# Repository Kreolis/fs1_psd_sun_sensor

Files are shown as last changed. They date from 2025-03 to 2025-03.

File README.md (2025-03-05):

# Foresail-1 PSS Sun Sensor

This repository contains the public available design files for the PSS sun sensor designed for the Foresail-1 Cubesat.

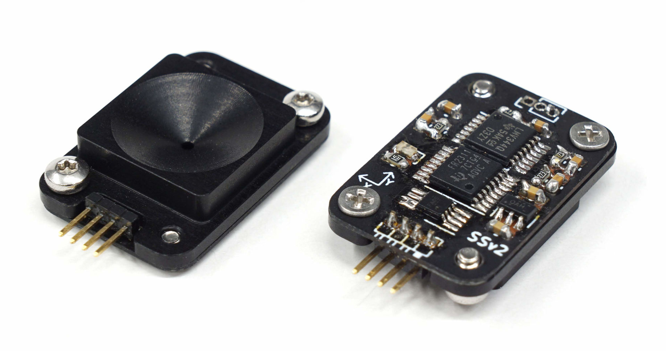
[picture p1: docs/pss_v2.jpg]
PSS Sun Sensor Prototype v2


The general characteristics of sensor design are:
- Dimensions: 24 mm × 16 mm × 6 mm
- Mass: 4 grams
- Panel mountedable into 14x14 mm hole with two M2 screws.
- Electrical connection by soldering on the panel PCB or by harness.
- FOV: ~100 degrees, resolution: 0.13°, accuracy: ±1°
- Refresh rate up to 100 Hz. (Sampling time: 4 ms + communication overhead)
- Can provide following data products:
    - Raw current measurements
    - Point & intensity measurements
    - Sun vector & intensity measurements
    - Angles & intensity measurements
- I2C digital serial interface (hardware version 3)
- RS-485 digital interface (hardware version 4)
- Low power consumption < 4 mW when active
- Nominal operating voltage: 3.6 - 3.8V: Can be extened easily to 2.0 – 5.5 V.

## Documentation

- [FS1 ADCS PSS Sun Sensor Design Document](docs/FS1p_ADCS_PSS_Sun_Sensor_Design_Document.pdf)
- [Version 3 schematic (I2C variant)](v3/pss_v3_schema.pdf)
- [Version 3 firmware source code](v3/fw)
- [Version 4 schematic (RS-485 variant)](v4/pss_v4_schema.pdf)
- [Version 4 firmware source code](v4/fw)
- [Calibration and test tools for PC](calibration)
- [Mechanical design files](mechanical)

## Licence

The design is licenced under [CERN Open Hardware Licence Version 2](LICENCE)

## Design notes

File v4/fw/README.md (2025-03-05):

# Building with Make:

The ti msp build tools can be downloaded from [here](https://www.ti.com/tool/MSP430-GCC-OPENSOURCE#downloads).
==Remember to set the `PREFIX` variable in the Makefile to point to your ti install location!==

requirements: msp-flasher mspdebugger msp430-elf-gcc

Usage:
- `make` compiles the PSD\_SUNSENSOR elf and ihex files
- `make flash` flashes with MSP430Flasher
- `make unlock` Erases user code from the device and unlocks debugger
- `make debug` Flashes the device, starts mspdebug gdb server and launches a gdb client

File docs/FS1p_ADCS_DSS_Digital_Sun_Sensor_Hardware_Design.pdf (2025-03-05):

## PSS Sun Sensor Design

FS1p ADCS PSS Sun Sensor Design

Responsible: Petri Niemelä Version date: 2023-10-18
Page: 1 / 23

# Foresail-1p

# PSS Sun Sensor Design

# Aalto University

## Department of Electronics and Nanoengineering

Page: 2 / 23

### Authors

Name | Worked with parts
Petri Niemelä | The whole document
Marius Anger | Foresail-1p revision 4

### Table of Contents

1 General | 4
1.1 Scope | 4
1.2 Applicable Documents | 4
1.3 Reference documents | 4
1.4 Abbreviations and acronyms | 4
2 Sensor Design | 5
2.1 Performance | 6
2.2 Sun vector estimation | 9
3 Electrical Design | 10
3.1 Electrical Interface | 10
3.2 Microcontroller | 10
3.2.1 Radiation Hardening | 11
3.3 Transimpedance Amplifiers | 11
3.4 Analog Digital Converter | 14
3.5 Power supply | 14
3.6 I2C bus isolation | 14
3.7 Operating environment | 15
4 Mechanical Design | 16
4.1 Mechanical Interface | 16
5 Digital interface | 17
5.1 I2C Commanding Protocol | 17
5.2 RS-485 Commanding Protocol | 17
5.3 Command set | 17
6 References and further reading | 19
7 Appendices | 21
7.1 Schematics | 21
7.2 Bill of Material | 21
7.3 PCB layout | 22

Page: 3 / 23

## 1 General

### 1.1 Scope

This document represents a detailed design of the PSS Sun Sensor designed for FORESAIL-satellites. This document applies for hardware version v3 (I2C variant) and v4 (RS-485 variant).

The public design files can be found from Github-repository: https://github.com/foresail/fs1_psd_sun_sensor

### 1.2 Applicable Documents

[AD-01] FS1 ADCS PSS Sun Sensor Prototype Test Plan (https://docs.google.com/document/d/1LfsjXxHAqfksmW_5qAY_K_lkndrjo7vK9R7hFGDcjuA/edit)

[AD-02] FS1 ADCS PSS Sun Sensor Qualification Test Report template (https://drive.google.com/open?id=1y2Mrd9W40DUWGKvcDPNy5vSXA1CmaDOZ_xgLSq9taWw)

FS1 Internal Communication Protocol DRAFT (https://docs.google.com/document/d/1XI1juZfPpQ4f6fcUQnDhy1BJxTMV3S1bdBzDqWCUd_g/edit)

### 1.3 Reference documents

[RD-01] Hamamatsu S5990-01 Two-Dimensional PSD
datasheet: https://www.hamamatsu.com/resources/pdf/ssd/s5990-01_etc_kpsd1010e.pdf

[RD-02] Texas Instrument’s MSP430FR231x Mixed-Signal Microcontrollers datasheet: http://www.ti.com/lit/ds/slase58d/slase58d.pdf

[RD-03] Texas Instrument’s OPAx340 Single-Supply, Rail-to-Rail Operational Amplifiers datasheet: http://www.ti.com/lit/ds/symlink/opa4340.pdf

### 1.4 Abbreviations and acronyms

ADC | Analog-to-Digital Converter
FRAM | Ferroelectric Random Access Memory
FOV | Field Of View
MCU | Microcontroller
PCB | Printed Circuit Board
PSD | Position Sensitive Detector/Device
TIA | Transimpedance Amplifier
WDT | Watchdog Timer

Page: 4 / 23

## 2 Sensor Design

The PSS sensor (Position Sensitive Sun sensor) is a light sensitive photodiode which produces a small current when exposed to light. The PSS differs from the normal photodiode by having four cathodes and one anode for one single large detector area. When the sensitive area is illuminated with a relatively small spot of light the produced currents are distributed depending on the position of the light spot. When the light spot is created using a pinhole structure the sensor can be used to measure direction/angle of the incoming light and thus the concept can be applied for making a sun sensor.

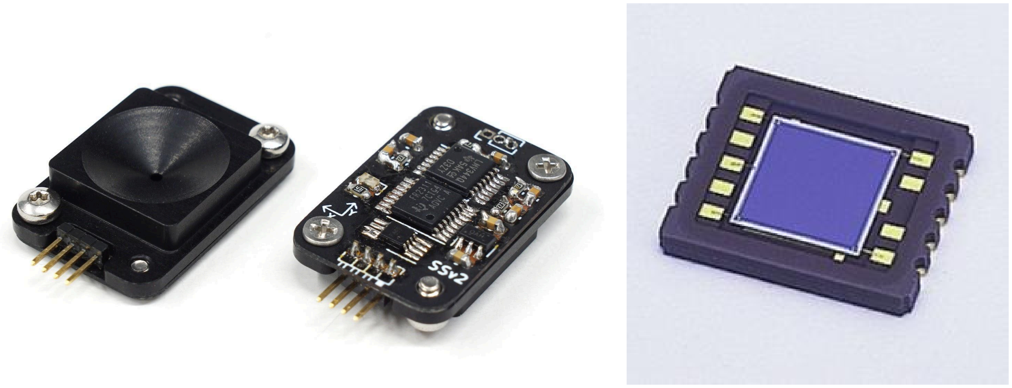
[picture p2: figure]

Figure 1: PSD Sun Sensor version 2 and Hamamatsu S5990-01 Position Sensitive Device

The used PSS, Hamamatsu S5990-1, (In Figure 1) is so called tetra-lateral type (pin-cushion type) that delivers improved position detection and linearity compared to other similar diodes. The sensor has a large 4 × 4 mm active area. [RD-01]

PSS sensors advantages in sun sensor application can be considered: simple electrical and mechanical design and easily achievable large Field of View (FOV). The sensor design's largest disadvantage is its sensitivity for stray light meaning that the sensor cannot discriminate between direct sunlight and reflected sunlight. Reflections, for example from moonshine or earthshine, cause bias error which cannot be easily eliminated from the measurements. Effect of this will be discussed later in detail.

The general characteristics of sensor design are:
- Dimensions: 24 mm × 16 mm × 6 mm
- Mass: 4 grams
- Panel mountable into 14x14 mm hole with two M2 screws
- Extension behind the panel: 3.1 mm
- Electrical connection by soldering on the panel PCB or by harness.
- FOV: ~100 degrees, resolution: 0.13°, accuracy: ±1° (discussed in the following sections)
- Refresh rate up to 100 Hz. (Sampling time: 4 ms + communication overhead)
- Can provide following data products:
- Raw current measurements
- Point & intensity measurements
- Sun vector & intensity measurements
- Angles & intensity measurements
- I

2C digital serial interface (applicable for hardware version 3)

Page: 5 / 23
- Maximum bus speed 400 kHz at 3.3V logic level.
- I

2C address can be configured via the command interface.
- The I

2C bus is isolated when the sensor is unpowered.
- RS-485 digital interface (applicable for hardware version 4)
- Follows reduced Foresail multi-drop RS-485 protocol definition
- Half duplex RS485 transceiver via MCU UART
- Low power consumption < 4 mW
- Sleep: 0.45 mA @3.6 V
- Sampling: 0.9 mA @3.6 V
- Peak sampling: TBD mA @3.6V
- In-rush current: TBD mA @3.6V
- Operating voltage: 2.0 – 5.5 V
- The standard version has a 3.3V LDO and designed operating voltage is around 3.6V.
- MSP430 can operate with voltages down to 1.8 V.

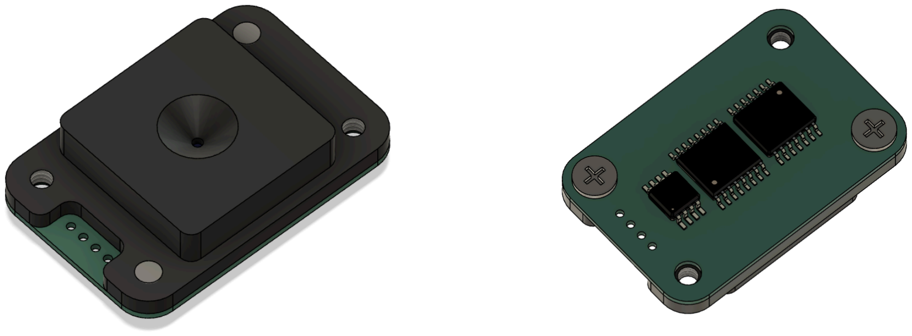
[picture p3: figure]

Figure 2: Front and back side of the PSD Sun Sensor assembly from CAD program.

### 2.1 Performance

The performance (FOV and accuracy) of the sensor is mainly determined by the geometry of the pinhole structure. The pinhole geometry is illustrated in the following figure. By adjusting the distance of the pinhole from the sensor. On the Foresail-1 PSD Sun Sensor the distance from photodiode to pin hole is 1.50 mm.

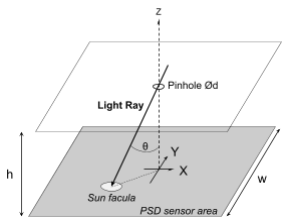
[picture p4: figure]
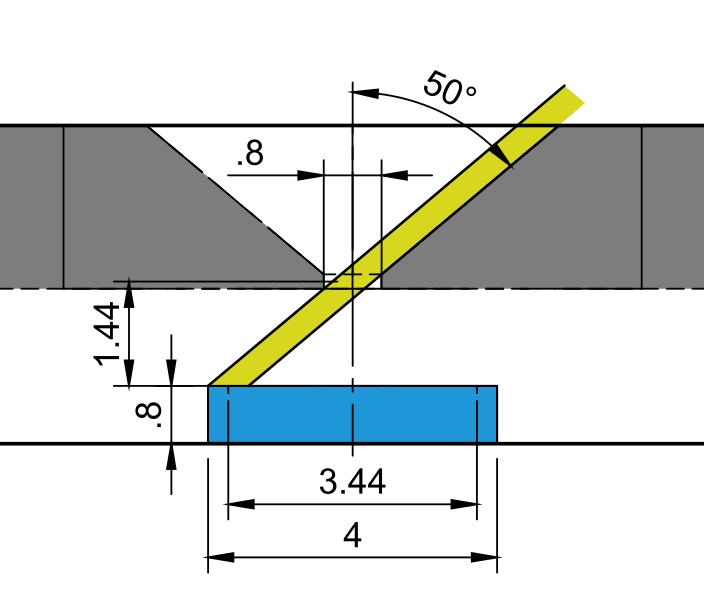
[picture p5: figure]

Figure 3: On left the sensor’s pinhole geometry illustrated in 3D. On the right the sensor’s actual pin hole geometry with dimensioning.

Page: 6 / 23

Field of View:
The maximum field of view of the sensor is determined by its tan( FoV/2 ) =

0.5*(w − d)
ℎ | =

0.5 * 3 mm
1.26 mm ⇒ FoV = 100°
In practice the sensor has an even larger FOV. (see calibration results)

Resolution:
When using 10 bits (1024 counts) per channel and because there are two channels per axis, each axis is “sampled” in 11-bit resolution. Thus, at the center of the sensor the theoretical resolution is:

θ = atan(

(3 mm / 1024)
1.26 mm

) ≃ 0. 134°

This resolution improves when moving toward the edge of the sensor. Smaller angle changes in the Sun direction causes larger changes in light spot position. At the edge the theoretical resolution is:

θ = atan(

0.5 * 3 mm
1.26 mm

) − atan(

0.5 * 3 mm * 511/512
1.26 mm

) ≃ 0. 055°

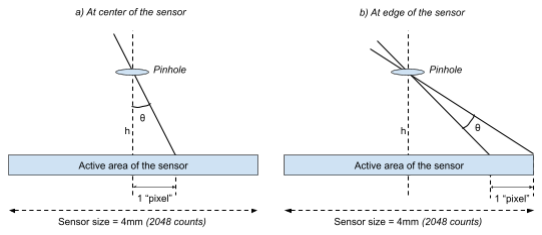
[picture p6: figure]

Figure 4: Resolution estimated using simplified pin hole geometry.

In theory, the resolution doesn’t depend on the size of the light spot until the light spot is clipped by the edge of the active area of the sensor. The output currents and the current distribution depends on the intensity of the light and the “mass center” of the light. If the light spot size is increased its mass center stays the same. Only the intensity (amount of light passing through the pinhole) changes. The sensor’s gain can be adjusted using for any pinhole

Real accuracy:
In theory the sensor could achieve better than 0.15° accuracy but in practice the accuracy is not that good and it is affected by numerous error sources. In this section some of those error sources are analyzed.
In practice the resolution of PSD based sensors varies between around 1 - 5°. If someone claims better accuracy (with similar FOV and single sensor) than this when using the same sensor technology, they most likely lie or don't tell the whole truth.

Error sources:
1) The sensor cannot differentiate between different sources of light: Sun, moon, Earth’s Albedo, specular reflections from the Earth’s surface. Discussed in detail in the next section.

Page: 7 / 23
2) The pinhole structure is not a perfect pinhole. Incoming light can reflect from the edge hole and cast a second light spot. Black anodisation aims to cope with this problem.
3) At high angles the cover glass can refract the light spot. This effect can be partially calibrated.
4) The light spot can reflect from the cover glass and bounce inside the sensor. The error caused by the reflections inside the sensors are tried to minimize by anodizing the sensor cover black.
5) The response of the PSD is not completely linear aka current distribution doesn’t map the light spot position perfectly. This happens both in axis and diagonally mapping. Hamamatsu’s tetra-lateral type (pin-cushion type) PSD aims to compensate for this.
6) The ADC is not perfect and it has noise on its results. According to the MCU’s datasheet ADC Effective error in 10-bit mode is ±2 LSB (least significant bits). Based on this the accuracy is less than 0.3°. ADC noise could be reduced by using oversampling because the sampling noise is gaussian by its nature. This is not seen beneficial because other error sources are more dominant and multi-sampling would just slow down the sampling.
7) Thermal expansion of the components is not considered. The surface temperature of the satellite can vary between -40°C and 40°C. The sensor cover should have a mirror finish on its front side to minimize heat load.
8) Sensor mounting on the satellite structure easily introduces a significant systematic error which is larger than the accuracy of the sensor. Calibrating the sensor position/orientation relative to the satellite’s coordinate system should be performed after final assembly but such test setup is not simple.

Effect of the straylight:
PSS’s greatest disadvantage is its incapability to differentiate between different light sources. The currents generated by different light sources (Sun, Earth, Moon shine and specular reflections from Earth’s surface) sums up together and cannot be separated from each other. Thus, Earth’s and Moon’s albedos add a bias error into Sun direction estimation if they are visible at the same time. Because each satellite’s face has a dedicated sun sensor and only the strongest signal is taken into consideration in sun vector determination, the Earth’s albedo affects the sun vector measurements only when the Sun and Earth are inside the same 90° FOV “pyramide”. This happens when the satellite is above 66’th latitude (north or south) and ±24° around the termination zone. The influence of Earth’s albedo is constantly on sun synchronous orbit, which Mean Local Time of the Ascending Node (LTAN) is between 04:24 - 08:36 and 16:36 - 19:24. These regions are illustrated in the Figure 5.

Page: 8 / 23

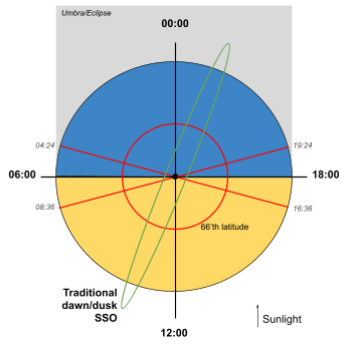
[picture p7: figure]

Figure 5: Orbit regions where PSD’s operation is affected by Earth’s albedo.

The effect of Earth’s albedo to the accuracy of PSD sun sensor is greatly discussed in Rober Valner’s bachelor’s thesis: http://dspace.ut.ee/bitstream/handle/10062/30981/Robert_Valner.pdf In his thesis he concludes that: “the net uncertainty of the measurements of the sensor is 2.5° with coverage probability of approximately 95%”

Intensity accuracy:
The intensity measurement of the sensor is relative and should not be used as absolute measurement. The sensor’s intensity output is the average of each channel's output in range from 0 to 1024. The reading highly depends on the sensor’s temperature due to photodiodes efficiency characteristics and temperature drift of the voltage reference.

The intensity reading itself could be also used to determine the sun angle using inverse cosine law and with temperature compensation using the MCU’s temperature sensor could provide better absolute accuracy but this is implemented because it’s not seen beneficial for an attitude control system as whole. The linearity of the intensity measurement is not known.

What could be improved?
Possible methods to improvement accuracy:
1. More sensors with smaller FOV
2. Add UV bandpass filter to remove the effect of albedo and specular reflections.

### 2.2 Sun vector estimation

The determination of the sun vector from multiple sun sensors can be done using following simple algorithm:
meas = get_all_sun_vectors()

sun_detected = false
sensor_i = arg_max(meas.intensity)
if meas[sensor_i].intensity > detection_threshold:

Page: 9 / 23

sun_direction = apply_rotation(sensor_i, meas[sensor_i].vector) sun detected = true

## 3 Electrical Design

The electrical design of the sensor is very simple. It consists of a PSD sensor itself (aka four channel photodiode), four transimpedance amplifiers and a MCU for analog to digital conversion and digital communication.

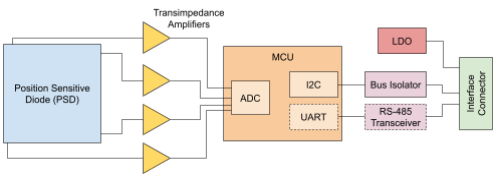
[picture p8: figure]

Figure: Block diagram of the sensor's electrical components and their connections.

### 3.1 Electrical Interface

The sensor’s electrical interface is described in the table below.

Table: Sensor pinout
Pin number | Pin name on version 3 | Pin name on version 4
1 | GND | GND
2 | VCC | VCC
3 | I2C SDA | RS-485 DATA+
4 | I2C SCL | RS-485 DATA-

On the PCB the electrical connection is done to the 1.27 mm pitch pin 4 hole connector footprint. To this footprint the electrical connection can be done by directly soldering the sensor on a PCB panel using a right angle 1.27mm pin header or by soldering a pigtail cable on it.

### 3.2 Microcontroller

The PSS’ MCU is Texas Instrument’s MSP430FR2311IPW16. MCU’s important features are: [RD-02]
- Small TSSOP-16 package
- Runs at 4 MHz
- 3.75KB of Program FRAM (Radiation Resistant and Nonmagnetic) + 1KB of RAM
- Internal 1.2V voltage reference
- 8 channel 10-Bit Analog-to-Digital Converter (ADC) with internal 1.5V voltage reference

Page: 10 / 23
- Optimized low power modes (32nA in shutdown)
- Wide support for serial communication protocols such as I

2C, UART etc.
- Internal brown-out detection circuit

The selected MCU has also internal opamp which could have been used for something.

### 3.2.1 Radiation Hardening

Following radiation hardening are considered in the design:

### 1. Usage of system FRAM memory:

The selected MCU uses FRAM technology for storing its firmware. The FRAM technology is known from its radiation hardness on a memory cell (SEU: Single Event Upsets). This doesn’t ensure complete radiation hardness against other types of single events. Single events can also happen in the memory controllers etc.

Also the sensor is vulnerable to destructive single events burnouts if no latching.

The dose tolerance of the MCU is not known and it could be generalized outside of a single batch.

### 2. Watchdog Timer:

Watchdog resets the MCU every ~40 seconds if the main loop stops running. Heartbeat timer tries to wake up the processor every 70 ms to execute the main loop.

### 3. Register refreshing by resetting:

Sensor initializes itself every 2 minutes in nominal state to refresh all internal peripheral registers.

### 3. Component-level power cycling:

The opamp’s power is supplied from MCU’s IO-pin which works as current limiter and load switch and it can be used to cycle on every reset.

### 4. Sensor Aluminium shielding

At the surface of the satellite, the sensor experiences a harsher radiation environment compared to the rest of the electronics on board inside the radiation shielding. To compensate this a little bit, the thickness of the aluminum sensor cover has not been minimized to give some protection against total dose effects. The only way to improve this more is to move the electronics beside the PSD photodiode itself inside the satellite.

### 3.3 Transimpedance Amplifiers

For PSD sensor current measurement the sensor board has four transimpedance amplifiers (TIA) to perform current-voltage conversion with predefined gain. The amplifier gain is set by the external resistor and adjusted depending on illumination levels, hole size etc. Photodiodes are in zero reverse bias configuration for improved sensitivity at low intensities. Additionally, a filtering capacitor is placed parallel on the feedback loop to cut-off frequencies above 100 Hz.

When the current is zero the opamp outputs the reference voltage and higher the current lower the output voltage is. The output voltage can be then measured by the ADC. MSP430’s internal voltage reference (VREF+) is used for the opamp. The precision of the voltage reference doesn’t affect the overall point position measurements. The possible reference voltage drift affects only absolute

Page: 11 / 23
intensity measurements and is the same for all the channels. The point position is calculated from the differences of absolute current measurement as defined in equation X, and thus, possible reference voltage drift won’t affect sun vector accuracy. The absolute illumination is not sure for sun vector determination. Also, the diode’s leakage current will vary based on the temperature.

On hardware version 4 (RS-485 variant), the MSP430’s internal voltage reference cannot be used due to pin mapping collision with an UART pin required for RS-485 transceiver. Thus, an external voltage reference is required for the opamps. There are no real requirements for the reference other than voltage should be such that the opamp doesn't need to drive till the rail voltage. Absolute stability is not required because the intensity measurements are already relative by their nature and the reference is shared between the channels. Also the voltage reference is connected to very high impedance (only opamps inputs), so the current draw is negligible. Thus, to keep the BOM and PCB layout simple a simple 1:1 resistor divider was chosen to generate 1.65 V reference. The resistor divider as voltage reference is sensitive for source voltage but in this case the 3.3V source voltage is regulated very close to the divider itself.

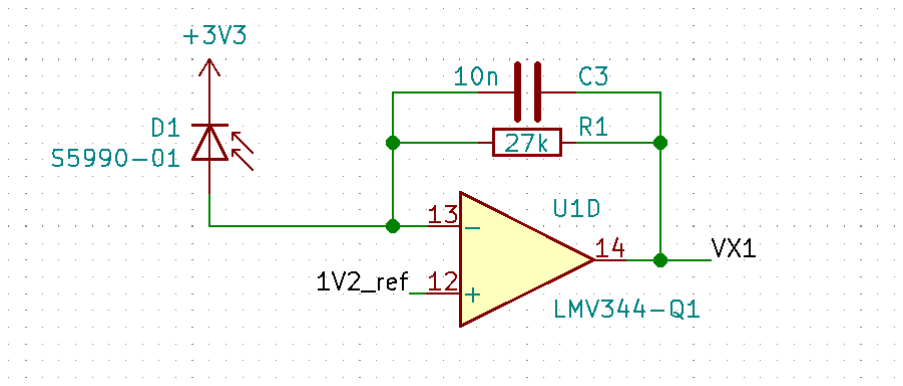
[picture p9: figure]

Figure 6: Simplified circuit diagram of a transimpedance amplifier.

The chosen operational amplifier is automotive quality LMV344-Q1 quad rail-to-rail output CMOS operational amplifier in small TSSOP-14 package [RD-03]. The opamp has relatively narrow bandwidth (1 MHz), low power consumption 100 µA (typical). Measured current consumption in dark: 230 µA. (0.83 mW @3.6 V)

Opamp’s positive rail is at 3.3 V and negative at GND. The opamp is powered from MCU’s GPIO pin thus can be turned to save even more power. This is possible due to the low power consumption of the opamp.

The response of the transimpedance amplifier circuit was simulated using LTspice simulation program. The simulation model is illustrated in Figure 7. The model was used to confirm the AC response of the filter (Figure 8). Also, an input waveform for the photodiode current source was generated using a simple Python script. The amplifier circuit’s time domain response when attach on a satellite spinning at 1 Hz can be seen in Figure 9.

Page: 12 / 23

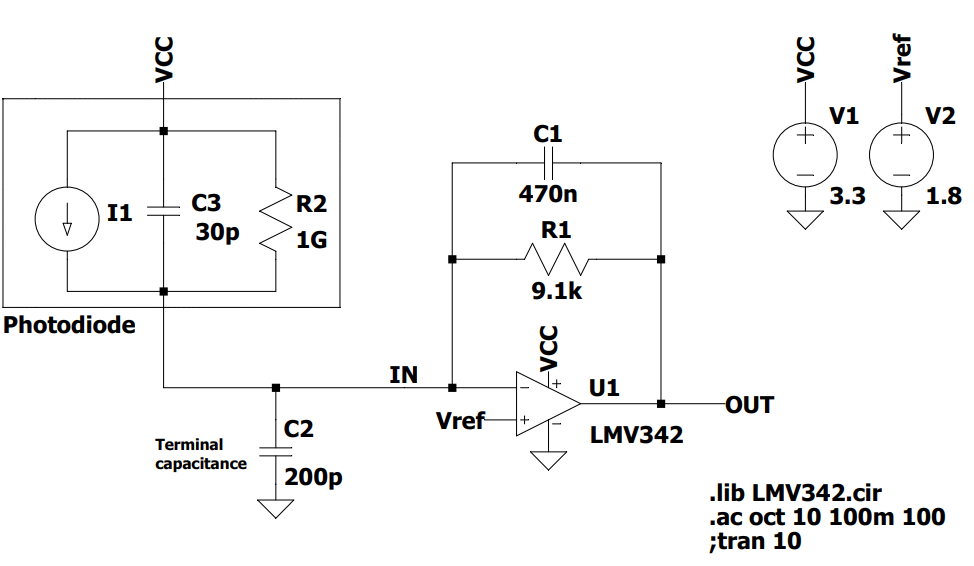
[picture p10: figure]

Figure 7: LTSpice model used to simulate the transimpedance amplifier transient and AC responses. (The used LMV342 opamp is identical LMV344 but has different number of channels)

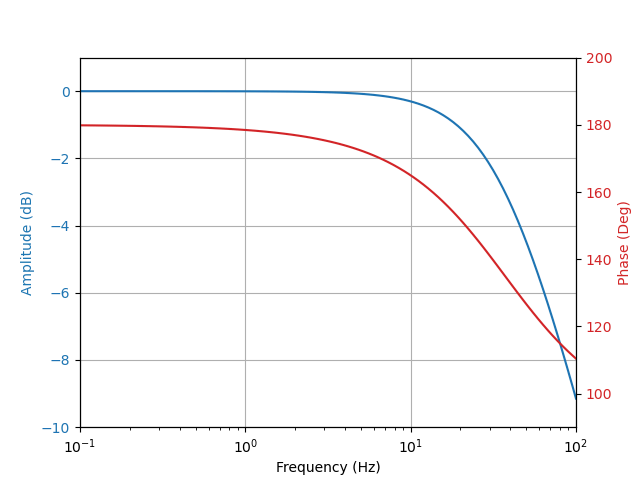
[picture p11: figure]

Figure 8: The AC response of the transimpedance filter. The -3dB cutoff frequency is around 37 Hz.

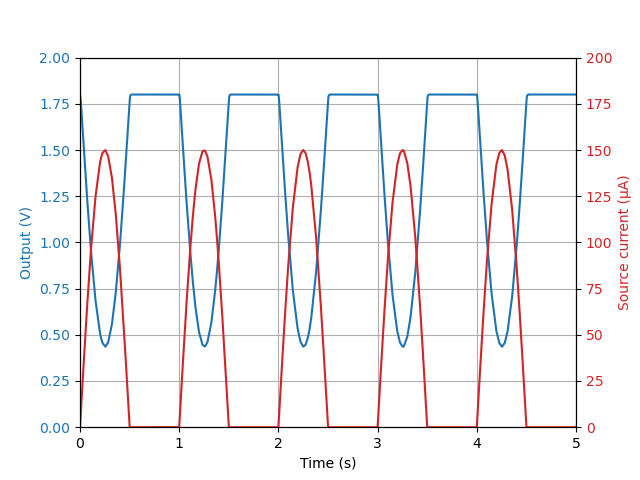
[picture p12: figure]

Figure 8: Transient response of the TIA for 1Hz (60 rpm) spin. The output voltage response is inverted compared to the produced current of the photodiode due to the reverse bias design. Small amount of smoothening can be seen on the trailing edge due to low pass filtering.

Page: 13 / 23

### 3.4 Analog Digital Converter

The analog to digital conversion is done using MSP430’s internal 8-channel 10-bit ADC and the analog lines are referenced against MSP430’s 1.2 V reference (VREF+) which is externally connected to ADC’s VEREF+ -pin.

The ADC samples the different voltage channels in sequence and not simultaneously. The small sample time difference is considered to be negligible for the precision of the sensor. For a satellite spinning at 1 Hz, the satellite attitude changes 1.1° during the 3 ms sampling time.

Temperature sensor: MSP430 has an internal temperature sensor which is connected to ADC’s channel 12. Temperature sensor voltage is compared to ADC’s internal 1.5 V reference. The maximum temperature the sensor can measure is roughly 170°C. Above this temperature the sensor voltage goes above 1.5 V.

ADC count to temperature is thus coefficient:
3. 35 mV/°C ⇒ (1500mV / 1024 counts) / 3. 35mV/°C = 4. 37° dC/count

Equation on the MCU:
T(°dC) = (ADCcount − calib) / 4 °dC/count + 300°dC

### 3.5 Power supply

The sensor is designed to take 3.6 V input voltage and has 3.3 V low dropout voltage (LDO) regulator on board. Lower voltages are possible down to 2.5V with the same opamp or down to 1.5 V the opamp is changed to a similar kind of with lower input voltage rating. The LDO can be also bypassed with a 0-ohm resistor if wanted.

### 3.6 I

### 2C bus isolation

Sun sensor uses SN74TVC3306 bus level translation IC as I

2C bus isolator to prevent stalling the I

2C bus when the sensor is not powered. The isolator also prevents the sensor from being powered via the SDA/SCL lines due to low power consumption of the MSP430 processor. The isolator IC is basically three individual NMOS transistors (also called dual voltage clamp) and can be considered robust design for higher radiation environment. The down side of this type of isolator is the 3.5 ohm high’ish series resistance.

Page: 14 / 23

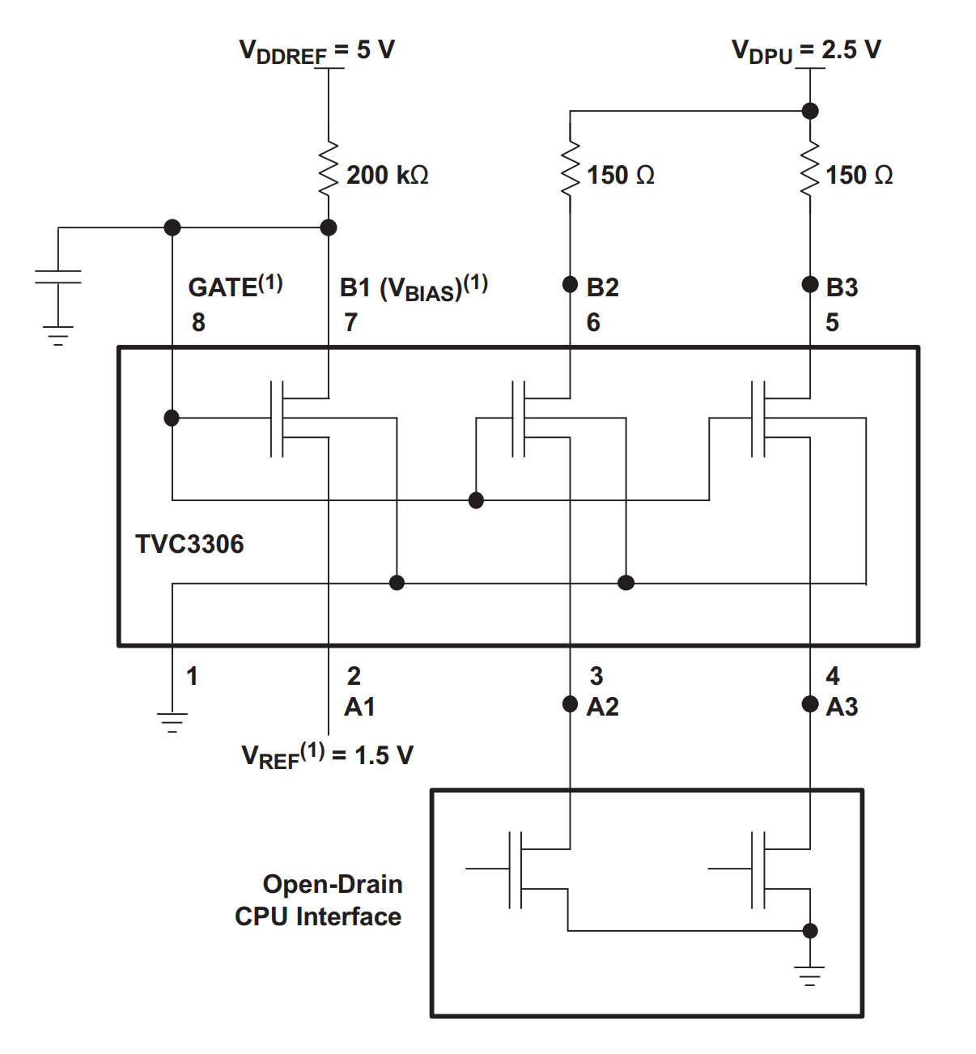
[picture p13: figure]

Figure 9: Internals of the SN74TVC3306 IC used for the I2C bus

### 3.7 Operating environment

The PSS are expected to encounter large temperature variations in the low earth orbit conditions on the surface of the satellite. On the surface of the satellite, sensors are exposed to direct sunlight and cold space in turns with very little thermal inertial and poor thermal conduction to the rest of the satellite's structure. It has been estimated that the surface temperatures of the cubesat in LEO will at least vary from -20 to 30 °C on every orbit and in the worst case -40°C to 60°C.

The recommended operating temperature ranges for each component can be seen in the following table. The most limiting recommended temperature range is for Hamamatsu's PSD diode whose lower temperature limit is -20°C. Low temperatures doesn’t inherently degrade the electrical performance of a diode but the diode’s packaging method might be the reason for the lowered rating. (Maybe the manufacturer hasn’t just performed the qualification test for lower temperatures.) There are no huge concerns to suspect that the diode would fail right after -20°C. Also, thermal vacuum verification tests with -40 to +100°C temperature range are performed for all the PSS assemblies at subsystem level.

Table: Off-the-self component environment ratings
Component | Recommended Operating Temperature
Hamamatsu S5990-01 | −20°C to +60°C
MSP430FR2311IPW16 | −40°C to +80°C
LMV344-Q1 | −40°C to +125°C
TLV71333P-Q1 | −40°C to +125°C
SN74TVC3306 | −40°C to +80°C

Page: 15 / 23

THVD14xx | −40°C to 125°C

The sensor PCBs are ordered with higher Epoxy glass transition temperature (Tg=170-180°C) to make sure the PCB can tolerate high temperature cycles and won’t fracture or de-laminate due to material expansion.

Note: A single case of sensor stopping working at temperatures higher than 50°C has been observed. The root cause of the problem was never investigated but it was clearly an analog side failure. The sensor recovered by itself when the temperature decreased below 50°C.

## 4 Mechanical Design

Sensor’s main structural component is the aluminum sensor cover which also works as the pin hole structure for the photodiode. The 0.5mm thick back PCB attaches to the sensor cover using two M2x2 screws and the whole assembly has been designed to be mounted on the panel (Aluminum plate or PCB).

The sensor cover has four M2 threaded holes in total. Two of these are used for attaching the PCB to the cover and other two are used to attach the whole assembly to the panel. Mounting to the panel can be done for example with two M2x4 screws. In Figure 10 the sensor’s overall dimensions and the locations of the attachment holes can be seen.

Either of the diagonals can be used for attaching the PCB and for sensor mounting. See preferred from Figures 1 and 2.

### 4.1 Mechanical Interface

The sensor’s mechanical interface can be seen in the figure below.

Page: 16 / 23

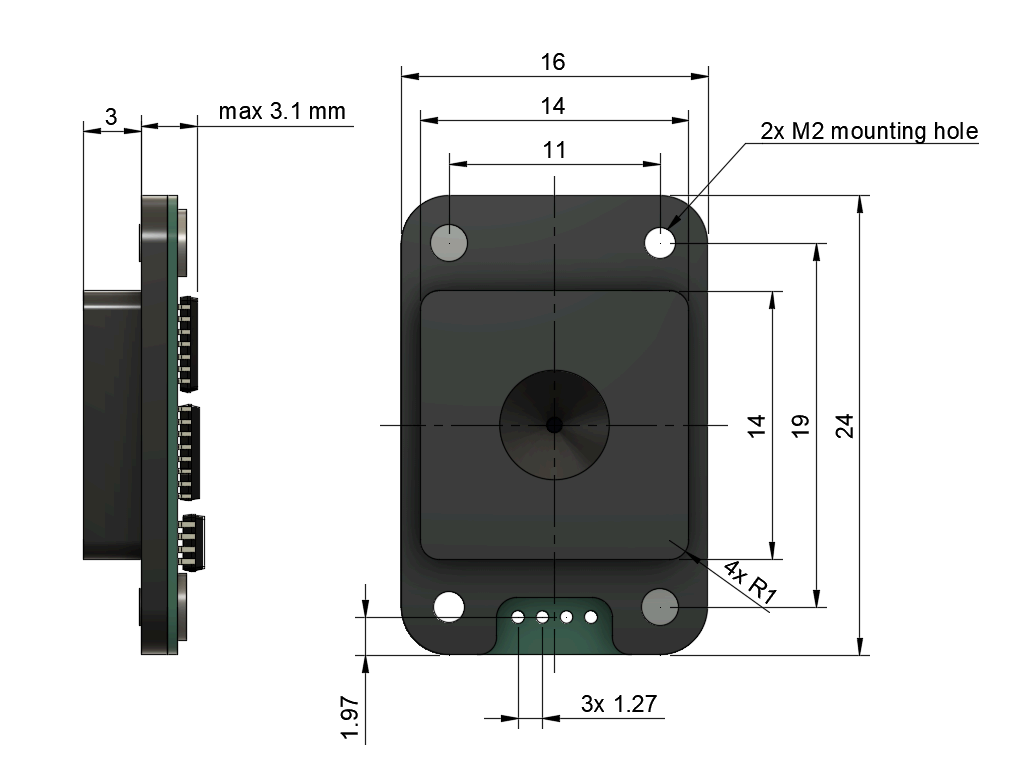
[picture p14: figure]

Figure 10: Required panel cut out for the module.The preferred holes for panel mounting are top-right and bottom-left holes.

The sensor is designed to be mounted on a 14x14mm size rectangular hole whose corner has 1mm rounding.

Note: Due to the small size of the sun sensor, the mounting/remounting accuracy of the sensor is not very high. Thus, the sensor's relative orientation to the satellite’s reference frame should be calibrated after the final integration.

## 5 Digital interface

This section defines the I

2C and RS-485 digital interfaces and the command set over the bus.

### 5.1 I

### 2C Commanding Protocol

Sensor’s digital interface uses the I

2C protocol where the sensor works as a slave. Default I

2C
address is 0x6A and the slave address can be set when reprogramming the sensor or using the I

2C
commands. Sensor implements a simple I

2C protocol which follows the standard I

2C data structure
and defines the first transmitted byte as a command byte which identifies the command or the response. The protocol commanding and response structure are illustrated in Figure 11.

Page: 17 / 23

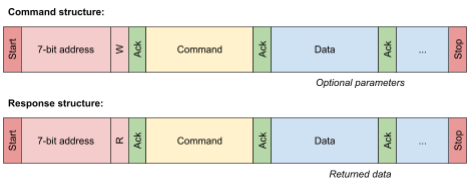
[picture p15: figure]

Figure 11: I

2C command and response structures

Remarks:
- The default address range for the sensors is: 0x4A - 0x4F
- If the I

2C master tries to read the response before the sensor is ready the slave will answer by sending 0xFF.

### 5.2 I2C Command set

List of PSD Sun Sensor commands and their functionalities

Remarks:
- Commands which do not return a special data structure return a status code with status command code (0x01).
- All the multi byte integers are in little endian format (most significant byte is last).
- If there is no I

2C communication on the bus in 2 seconds the MCU will turn off the opamp, voltage references and ADC to save power and unbiased the analog components.

0x01: Status
Read len: 1
Returns response code RSP_OK (0xF0) or RSP_SLEEP (0xF1).

0x03: Get Raw
Runs measurement sequence and returns raw current readings. Read len: 9

typedef struct { // size() = 8 bytes
uint16_t vx1; // Range: 0 - 1024 uint16_t vx2; // Range: 0 - 1024 uint16_t vy1; // Range: 0 - 1024 uint16_t vy2; // Range: 0 - 1024 } raw_measurements_t;

0x04: Get Position
Runs measurement sequence and returns measured light sport position and intensity.

typedef struct { // size() = 6 bytes
int16_t x; // -1024 - +1024

Page: 18 / 23

int16_t y; // -1014 - +1024 uint16_t intensity;
} position_measurement_t;

0x05: Get Angles
Runs measurement sequence and returns measured angles and intensity.

typedef struct { // size() = 6 bytes
int16_t ax; // Desidegrees int16_t ay;
uint16_t intensity;
} angle_measurement_t;
Note: The command uses 128 items look-up table and linear interpolation for angle calculation.

0x06: Get Vector
Runs measurement sequence and returns measured sun vector and intensity.
typedef struct { // size() = 8 bytes
int16_t x, y, z;
uint16_t intensity;
} vector_measurement_t;
Note: The reported vector is a direction vector toward the Sun aka signs of the X and Y point positions have been flipped.

0x07: Get All
Runs measurement sequence and returns all three data types listed above (raw, position, angles) Generally used for testing and verification purposes.
Read len: 21

0x08: Get Temperature
Return MCU temperature as 16-bit signed integer in desi-celsiuses aka 23.5°C = 235. Read len: 3 Sampling the temperature takes 1.54ms!

Note: If the temperature calibration offset is set to 0. This function will return the raw ADC count.

0x10: Set Calibration
Set calibration structure.
typedef struct {
int16_t offset_x, offset_y; int16_t height;
int16_t samples;
int16_t temperature_offset; } calibration_t;

0x11: Get Calibration
Returns the same calibration structure as described for “Set Calibration” command. Read len: 11

0x12: Set LUT
Set angle look up table values.
TBC

Page: 19 / 23

0xE8: Set I2C Address
Set a new I2C address for the sensor. To be applied a power cycling is required.

Note: Exact sampling time of sensor depends on the temperature due to temperature dependency of the internal clock.

### 5.3 RS-485 Commanding Protocol

Sensor’s digital interface uses the RS485 protocol where the sensor works as a client on the bus. Default RS485 address is 0xA5 and the address has to be set during the flashing of the device. Sensor implements the Foresail RS485 bus protocol. The protocol message scheme for commanding and response is illustrated in Figure 12.

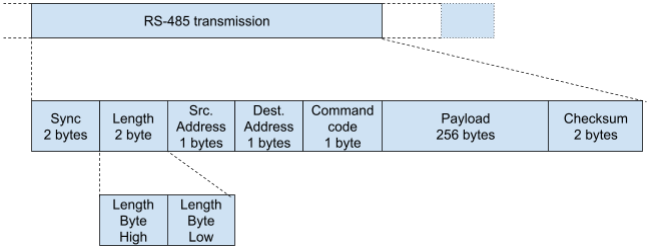
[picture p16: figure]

Figure 12: RS485 communication scheme

Remarks:
- The default address range for the sensors is: 0xA5 - 0xAA
- In the data stream the big-endian format shall be used unless specified. Most significant byte first must be sent for every multibyte word.

### 5.2 RS485 Command set

PSD Sun Sensor commands for RS485 are slightly different as less memory could be used for them as the bus implementation takes up more space.
Additionally, the commands have been unified as much as possible with the digital sun sensor (FS1p ADCS Digital Sun Sensor Hardware Design). (https://docs.google.com/document/d/1M4EdYB_b5ulZ9_kio8c96CQkCGD8mta-0tUQDGEhYco/edit?pli=1)

Remarks:
- Commands which do not return a special data structure return a status comman with status code.
- OK | = 0xF0
- SLEEP | = 0xF1
- UNKOWN_COMMAND | = 0xF2
- INVALID_PARAM | = 0xF3
- ERROR | = 0xF4

Page: 20 / 23
- SAMPLING_ERROR | = 0xF5
- DIVISION_ERROR | = 0xF6
- NOT_ODD | = 0xF7
- CLAC_ERROR | = 0xF8
- All the multi byte integers are in little endian format (most significant byte is last).

0x01: Get Status
Read len: 1
Returns response code RSP_OK (0xF0) or RSP_SLEEP (0xF1).

0x02: Get Raw
Runs measurement sequence and returns raw current readings. Read len: 9

typedef struct { // size() = 8 bytes
uint16_t vx1; // Range: 0 - 1024 uint16_t vx2; // Range: 0 - 1024 uint16_t vy1; // Range: 0 - 1024 uint16_t vy2; // Range: 0 - 1024 } raw_measurements_t;

0x03: Get Position
Runs measurement sequence and returns measured light sport position and intensity.

typedef struct { // size() = 6 bytes
int16_t x; | // -1024 - +1024
int16_t y; | // -1014 - +1024
uint16_t intensity;
} position_measurement_t;

0x04: Get Vector
Runs measurement sequence and returns measured sun vector and intensity.
typedef struct { // size() = 8 bytes
int16_t x, y, z;
uint16_t intensity;
} vector_measurement_t;
Note: The reported vector is a direction vector toward the Sun aka signs of the X and Y point positions have been flipped.

0x07: Get Temperature
Return MCU temperature as 16-bit signed integer in desi-celsiuses aka 23.5°C = 235. Read len: 3 Sampling the temperature takes 1.54ms!

Note: If the temperature calibration offset is set to 0. This function will return the raw ADC count.

0xA1: Get Config
Get config values of specified command.
Following commands are available for the PSD:
CALIBRATION = 0xB1

Page: 21 / 23
0xA2: Set Config
Set config of specified type to the PSD. Following types are available: CALIBRATION = 0xB1

typedef struct {
int16_t offset_x, offset_y; int16_t height;
int16_t samples;
int16_t temperature_offset; } calibration_t;

## 6 References and further reading

References outside of the project:
1. P. Rodrigues, P. Ramos, “Design and characterization of A sun sensor for the SSETI-ESEO project”
http://citeseerx.ist.psu.edu/viewdoc/download?doi=10.1.1.515.3785&rep=rep1&type=pdf
2. C. Avsar, J. Lieb, W. Frese, M. Herfort, and S.Trowitzsch, “Verification of a new two-dimensional sun sensor with digital interface on a sounding rocket.” http://rexusbexus.net/wp-content/uploads/2015/06/tupex-3_sse_symposium_paper_expert_panel_version.pdf (http://rexusbexus.net/wp-content/uploads/2015/06/tupex-3_sse_symposium_paper_expert_panel_version.pdf)
3. L. Lin, Z. Sitong, T. Luyang, W. Dong,“Sun sensor design and test of a micro satellite”, https://www.jvejournals.com/article/17518
4. D. Faizullin, K. Hiraki, HORYU-IV team, M. Cho, “Optimization of a Sun Vector Determination for Pinhole Type Sun Sensor”, http://oaji.net/articles/2017/1330-1507024153.pdf

Page: 22 / 23

## 7 Appendices

### 7.1 Schematics

Version 3

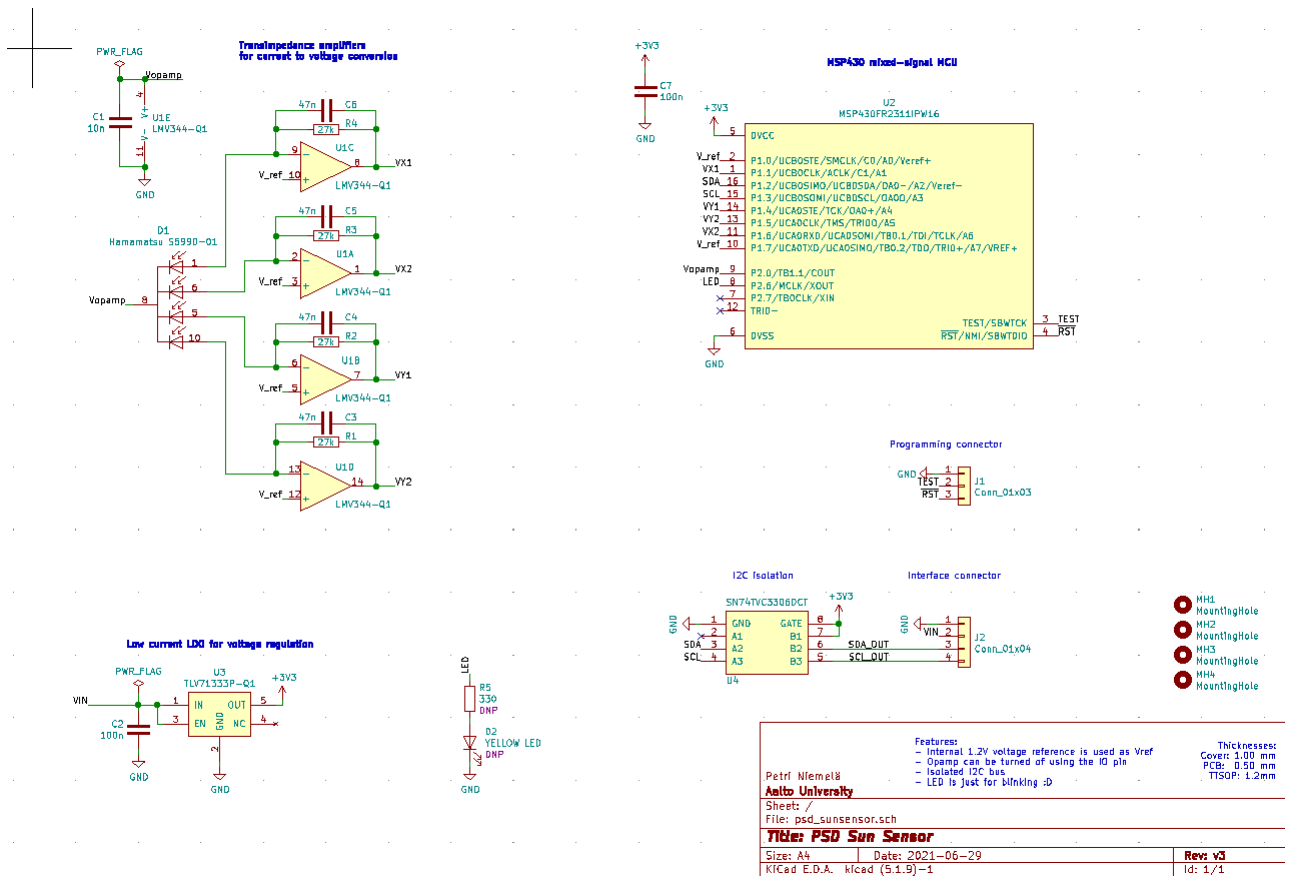
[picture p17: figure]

### 7.2 Bill of Material

Refs | Qty | Manufacturer | Name | Description/Comment
U1 | 1 | Texas Instruments | LMV344-Q1 | Automotive Grade Rail-to-Rail Output CMOS Op Amp
U2 | 1 | Texas Instruments | MSP430FR2311IPW16R | 16-bit Microcontrollers - MCU 16 MHz Ultra-Low-Power Microcontroller
U3 | 1 | Texas Instruments | TLV71333P | LDO Voltage Regulators Automotive Capacitor-Free 150mA Low-Dropout (LDO) Regulator
U4 | 1 | Texas Instruments | SN74TVC3306DCUR | Dual Voltage Clamp
C2,C7 | 2 | Generic | 100 nF 0603 SMD Capacitor | C0G and automotive grade

Page: 23 / 23

C1,C3, C4,C5, C6 | 5 | Generic | 10 nF 0603 SMD Capacitor | C0G and automotive grade
R1,R2, R3,R4 | 4 | Generic | 9k1 ohm 0603 SMD Resistor | Automotive grade
R5 | 1 | Generic | LED current limit 0603 SMD resistor | Do not populate on FM
D2 | 1 | Generic | Yellow 0603 SMD LED | Do not populate on FM
D1 | 1 | Hamamatsu | S5990-01 | Position Sensitive Detector (diode)
MH1, MH3 | 2 | Generic | A4 stainless steel M2 x 4mm pan head screw | Non magnetic!
MH2, MH4 | 2 | Generic | A4 stainless steel M2 x 2mm pan head | Non magnetic!

### 7.3 PCB layout

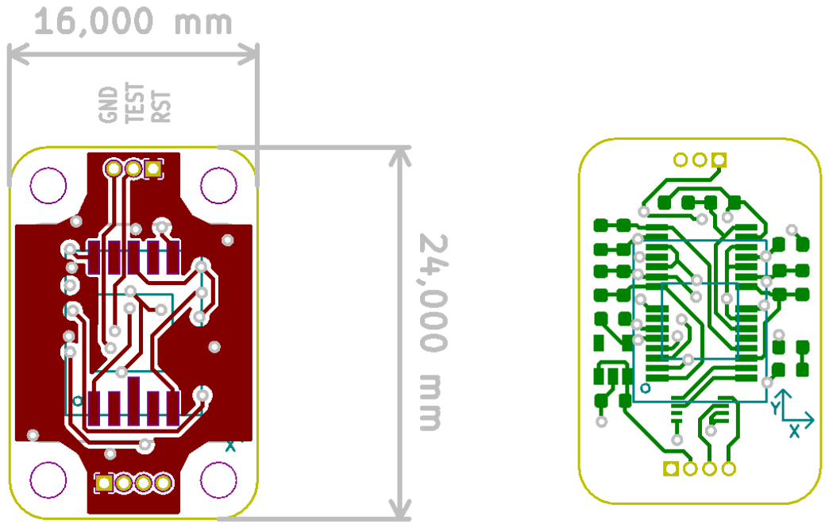
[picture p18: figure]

PCB front-side and back-side of hardware version 3

- Dimension: 16 mm × 24 mm
- PCB thickness: 0.5 mm

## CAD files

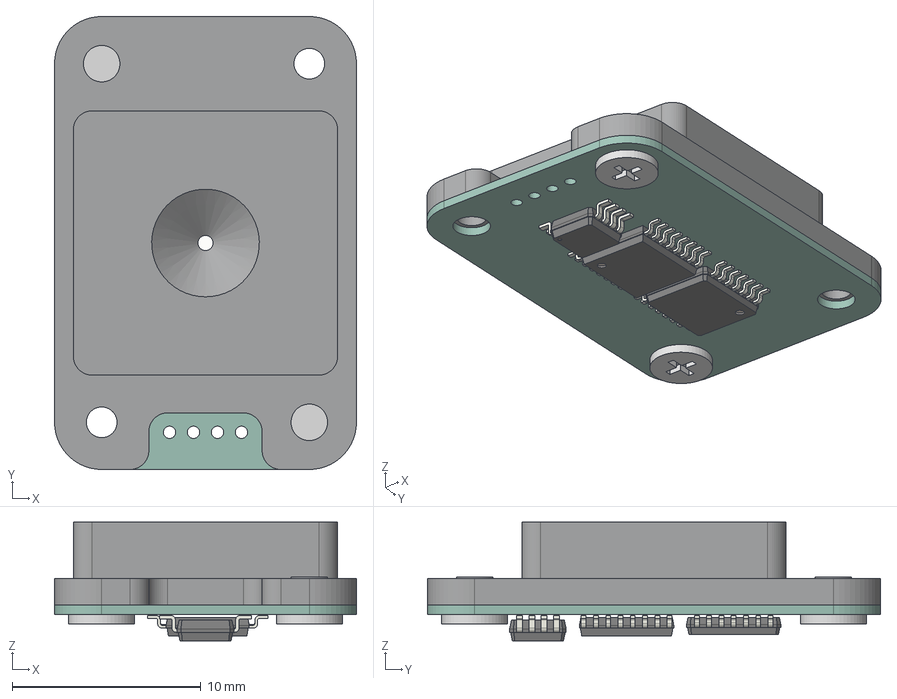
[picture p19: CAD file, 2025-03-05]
mechanical/pss_sun_sensor.step
16.0 x 24.0 x 6.30 mm
Simplfied PCB
Diode
Resin Window
Index Mark
Cover
M2x2 D3.5x0.5 x 2

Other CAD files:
v4/fw/Release/bus/bus.obj
v4/fw/Release/platform/timestamp.obj
v4/fw/Release/bus/bus_frame.obj
mechanical/PSS Sun Sensor.f3z

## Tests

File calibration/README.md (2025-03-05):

# Calibration tools for PSS Sun Sensors

- `pss.py` has implementation to command the PSS Sun Sensor over FTDI 232H cable
   and also command line utility perform certain tasks from the command line.
- `meas.py` has calibration measurement routine. For sensors.
- `plot.py` has scripts to plot calibration measurements.
- `fit.py` has script to calculate calibration values from the measurements.
- `lut.py` has script to generate a tangent lookup table.

## PSS Test Tool

```
usage: pss.py [-h] [--addr ADDR] [--rate RATE] [--raw] [--point] [--vector] [--angles] [--all] [--temp] [--scan] [--calib] [--set_offset SET_OFFSET SET_OFFSET SET_OFFSET] [--set_temp SET_TEMP] [--set_addr SET_ADDR]

PSS test tool

optional arguments:
  -h, --help            show this help message and exit
  --addr ADDR, -a ADDR  Sensor I2C address
  --rate RATE, -r RATE  Sampling rate
  --raw                 Sample raw data
  --point               Sample point data
  --vector              Sample vector data
  --angles              Sample angle data
  --all                 Sample all data types
  --temp                Sample temperature types
  --scan                Scan responsive sensors
  --calib               Get calibration values
  --set_offset SET_OFFSET SET_OFFSET SET_OFFSET
                        Set position offset and height
  --set_temp SET_TEMP   Set temperature offset
  --set_addr SET_ADDR   Set sensor I2C address
```

**Examples:**
Scan the whole I2C address space for PSS Sun Sensors
```
$ ./pss.py --scan
```

Read sensor temperature
```
$ ./pss.py --temp
23.6 °C
24.0 °C
24.0 °C
24.0 °C
```

Read light point position
```
$ ./pss.py --point --adrr 0x4C
1303 -1303     2
1024 -2048     2
1024 -1365     3
1303 -1303     2
1024 -1024     3
1228 -1228     2
1592 -1592     2
1303 -1303     2
```

Change PSS I2C address
```
$ ./pss.py --addr [old] --set_addr [new]
```

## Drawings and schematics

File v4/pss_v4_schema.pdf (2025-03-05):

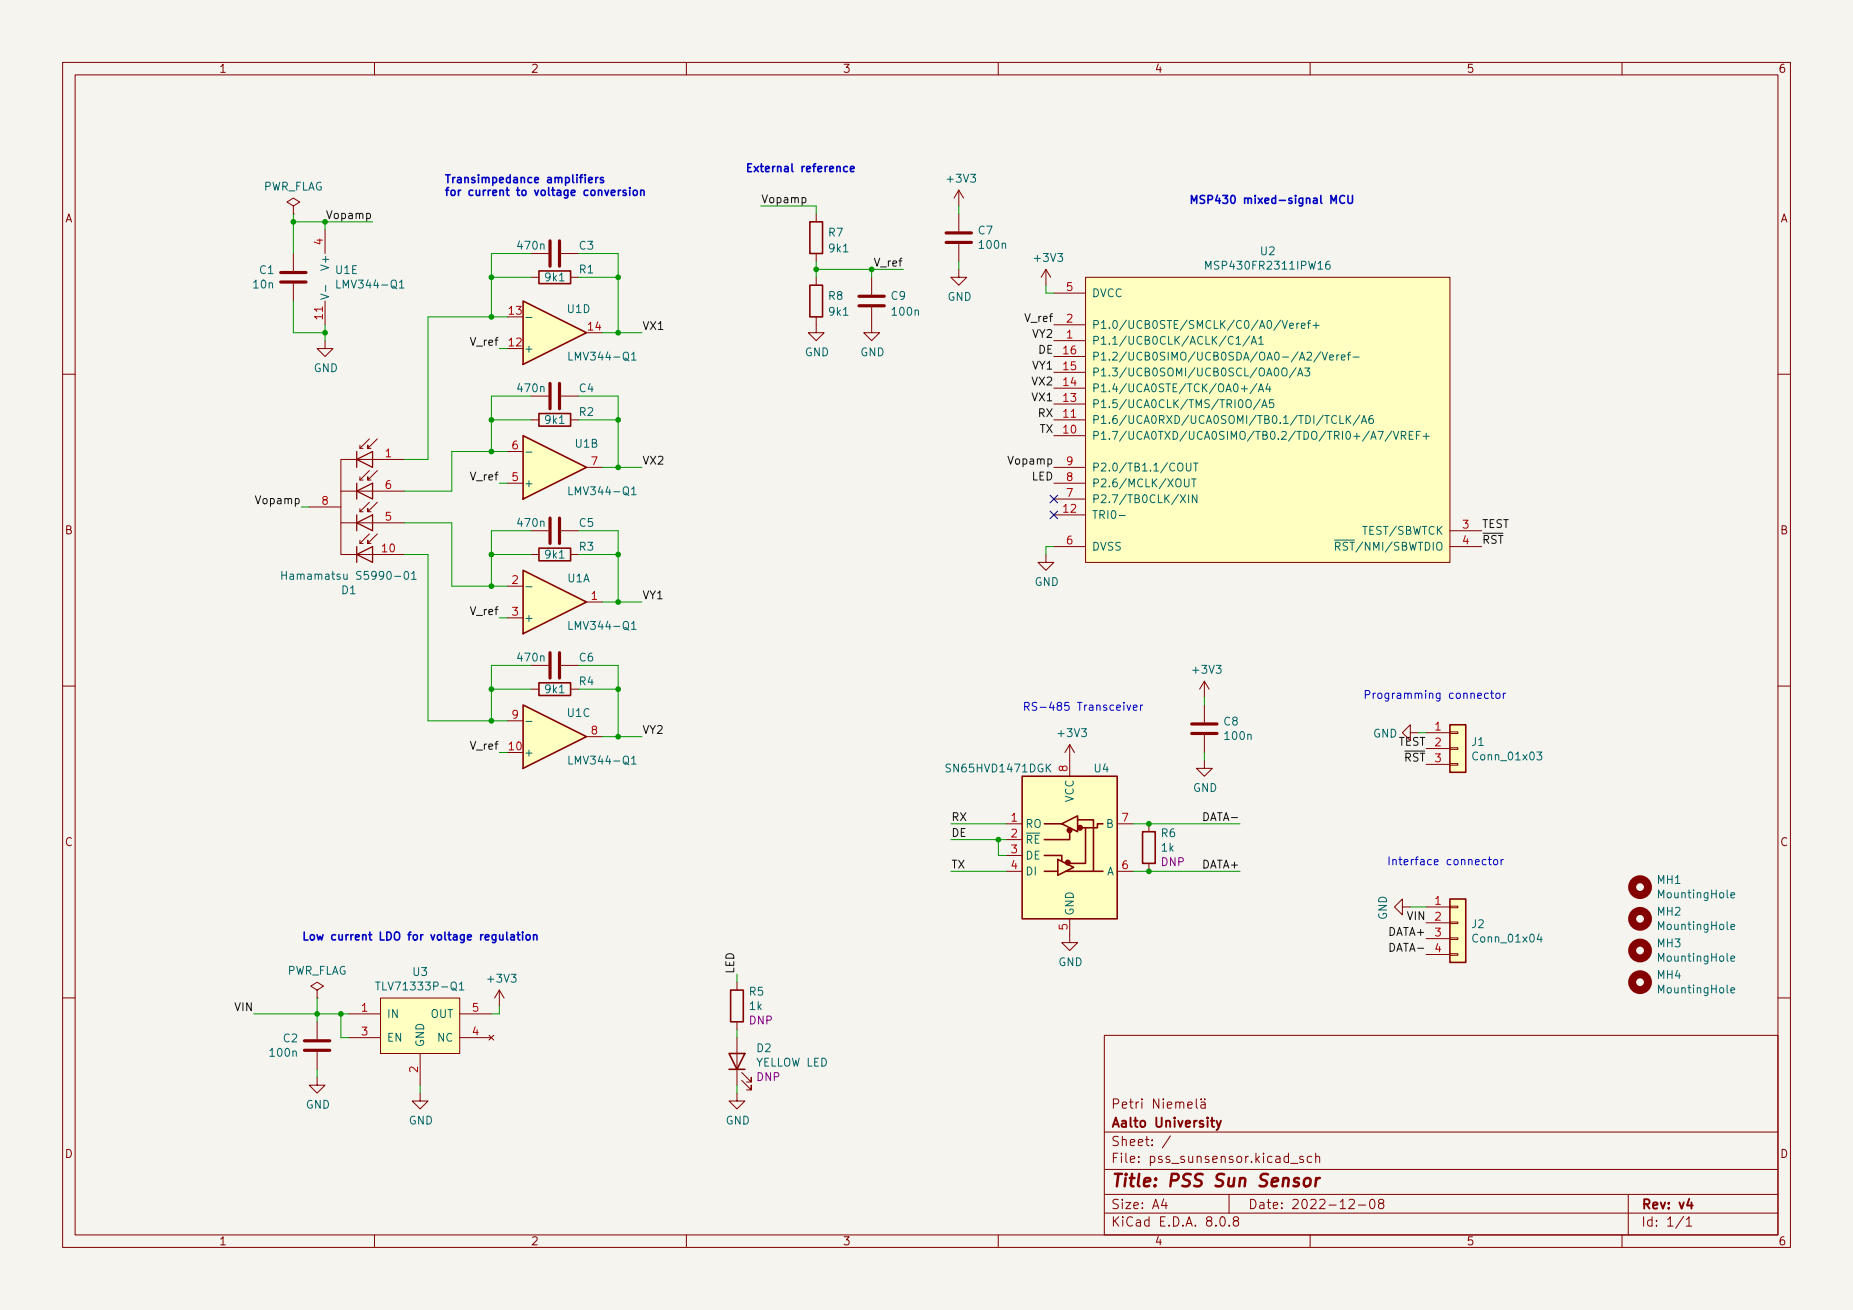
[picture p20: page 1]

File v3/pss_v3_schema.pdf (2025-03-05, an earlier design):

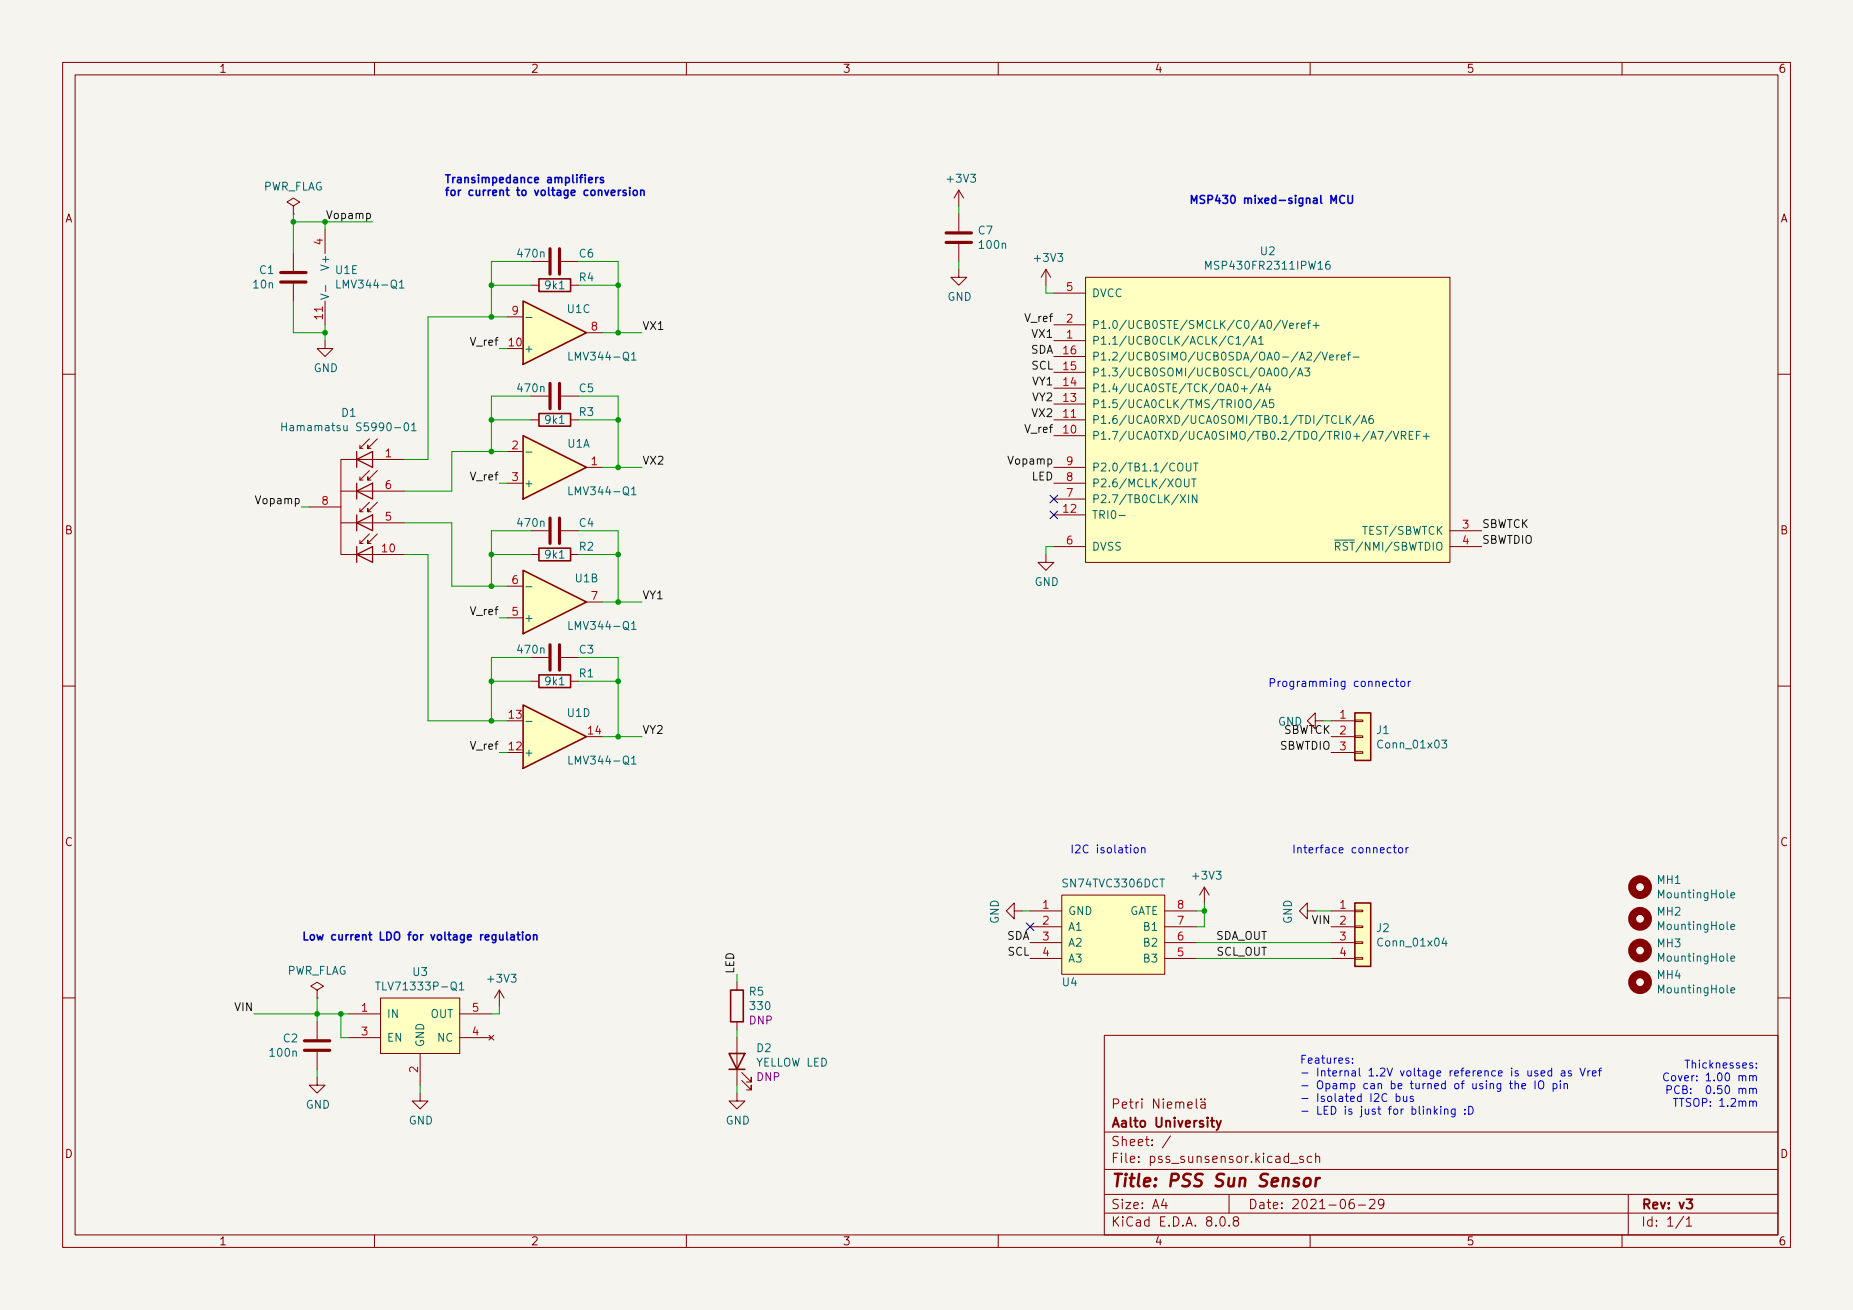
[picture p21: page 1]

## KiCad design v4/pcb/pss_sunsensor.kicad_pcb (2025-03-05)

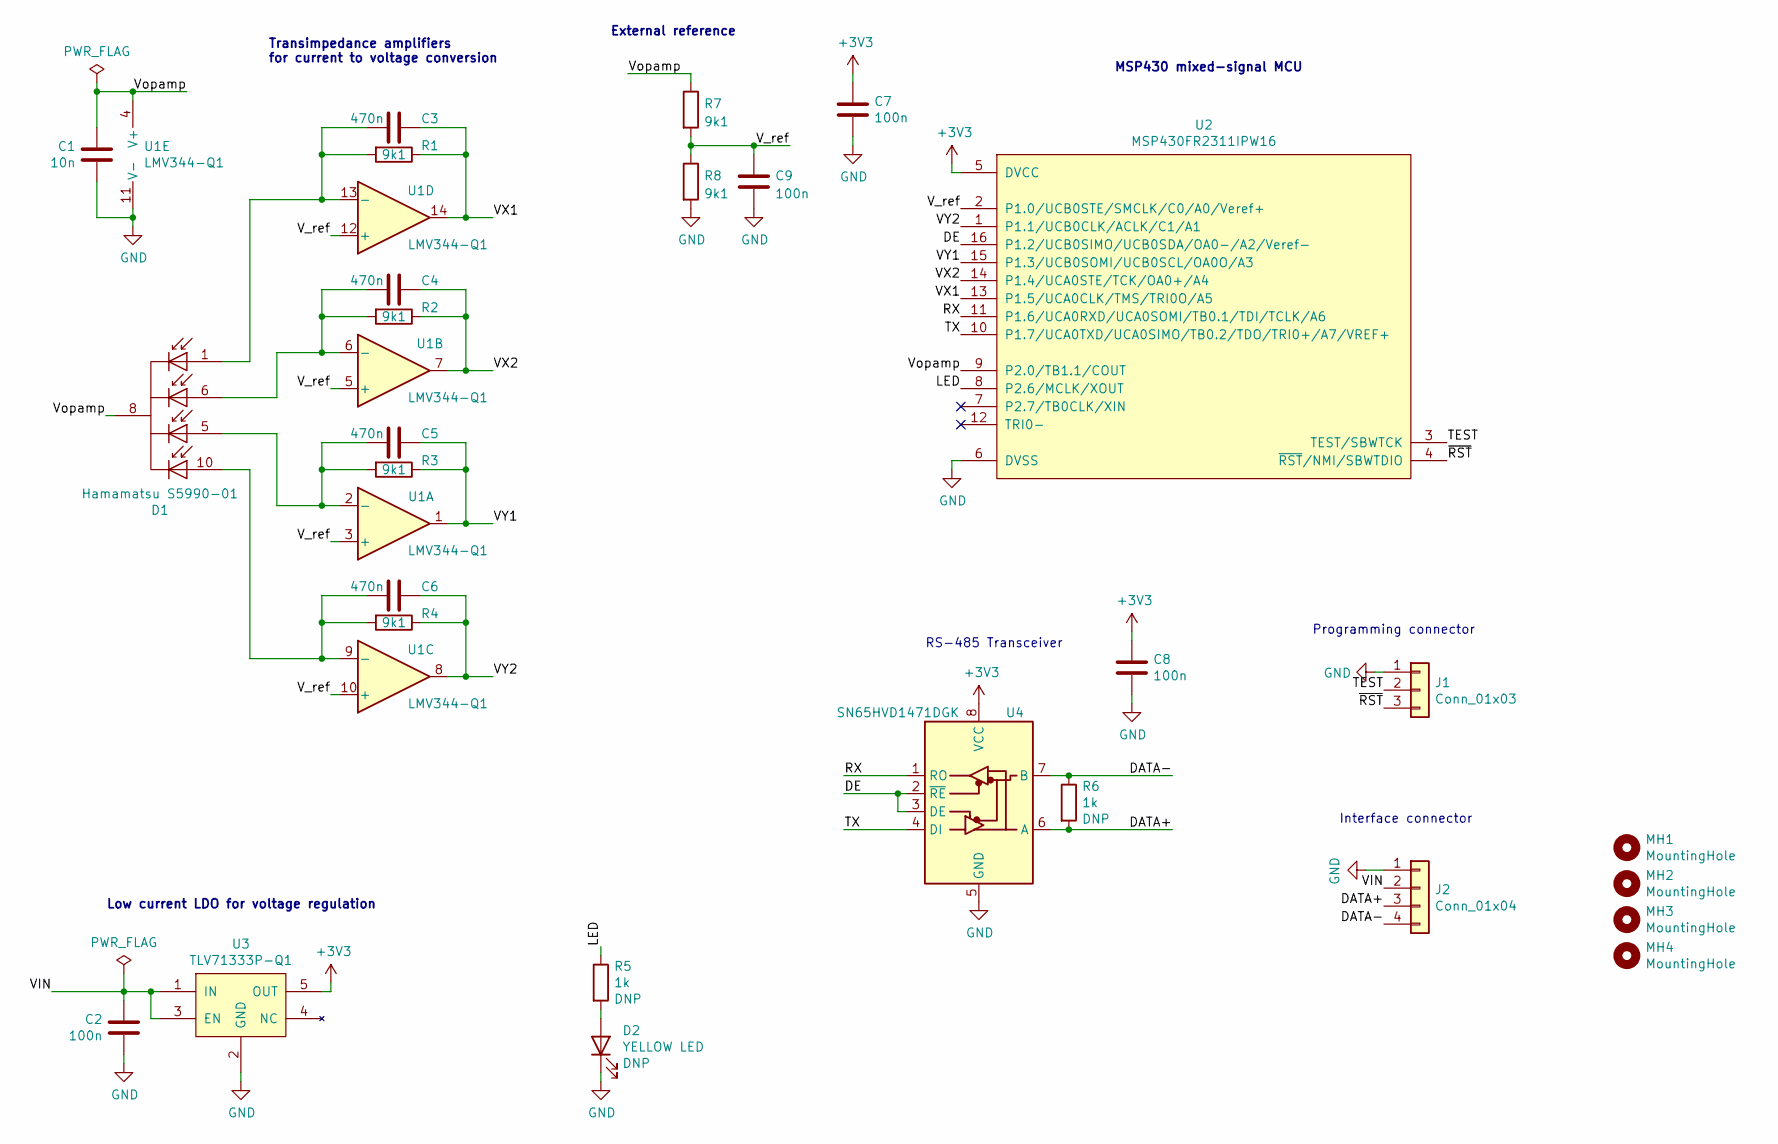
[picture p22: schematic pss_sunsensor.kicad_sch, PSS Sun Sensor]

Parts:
C1: 10n; C_0402_1005Metric
C2, C7, C8, C9: 100n; C_0402_1005Metric
C3, C4, C5, C6: 470n; C_0402_1005Metric
D1: Hamamatsu S5990-01; Hamatsu_S5980
D2: YELLOW LED; LED_0402_1005Metric
J1: Conn_01x03; PinHeader_1x03_P1.27mm_Vertical
J2: Conn_01x04; PinHeader_1x04_P1.27mm_Horizontal
MH1, MH2, MH3, MH4: MountingHole; MountingHole_2.2mm_M2
R1, R2, R3, R4, R7, R8: 9k1; R_0402_1005Metric
R5: 1k; R_0402_1005Metric
R6: 1k; R_0603_1608Metric
U1: LMV344-Q1; TSSOP-14_4.4x5mm_P0.65mm; Mouser 595-LMV344IPWRQ1
U2: MSP430FR2311IPW16; TSSOP-16_4.4x5mm_P0.65mm; Mouser 595-P430FR2311IPW16R
U3: TLV71333P-Q1; SOT-23-5; Mouser 595-TLV71333PQDBVRQ1
U4: SN65HVD1471DGK; VSSOP-8_2.4x2.1mm_P0.5mm

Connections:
+3V3: C7.2, C8.2, U2.5 (DVCC), U3.5 (OUT), U4.8 (VCC)
/DATA+: J2.3, R6.2, U4.6 (A)
/DATA-: J2.4, R6.1, U4.7 (B)
/DE: U2.16 (P1.2/UCB0SIMO/UCB0SDA/OA0-/A2/Veref-), U4.2 (~RE), U4.3 (DE)
/LED: R5.1, U2.8 (P2.6/MCLK/XOUT)
/RX: U2.11 (P1.6/UCA0RXD/UCA0SOMI/TB0.1/TDI/TCLK/A6), U4.1 (RO)
/TEST: J1.2, U2.3 (TEST/SBWTCK)
/TX: U2.10 (P1.7/UCA0TXD/UCA0SIMO/TB0.2/TDO/TRI0+/A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), U4.4 (DI)
/VIN: C2.2, J2.2, U3.1 (IN), U3.3 (EN)
/VX1: C3.1, R1.1, U1.14, U2.13 (P1.5/UCA0CLK/TMS/TRI0O/A5)
/VX2: C4.1, R2.1, U1.7, U2.14 (P1.4/UCA0STE/TCK/OA0+/A4)
/VY1: C5.1, R3.1, U1.1, U2.15 (P1.3/UCB0SOMI/UCB0SCL/OA0O/A3)
/VY2: C6.1, R4.1, U1.8, U2.1 (P1.1/UCB0CLK/ACLK/C1/A1)
/V_ref: C9.2, R7.2, R8.1, U1.3 (+), U1.5 (+), U1.10 (+), U1.12 (+), U2.2 (P1.0/UCB0STE/SMCLK/C0/A0/Veref+)
/Vopamp: C1.2, D1.8 (Cathode), R7.1, U1.4 (V+), U2.9 (P2.0/TB1.1/COUT)
/~RST: J1.3, U2.4 (~RST/NMI/SBWTDIO)
GND: C1.1, C2.1, C7.1, C8.1, C9.1, D2.1 (K), J1.1, J2.1, R8.2, U1.11 (V-), U2.6 (DVSS), U3.2 (GND), U4.5 (GND)
unnamed: C3.2, D1.1 (Anode_X1), R1.2, U1.13 (-)
unnamed: C4.2, D1.6 (Anode_X2), R2.2, U1.6 (-)
unnamed: C5.2, D1.5 (Anode_Y1), R3.2, U1.2 (-)
unnamed: C6.2, D1.10 (Anode_Y2), R4.2, U1.9 (-)
unnamed: D2.2 (A), R5.2

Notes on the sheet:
RS-485 Transceiver
Transimpedance amplifiers for current to voltage conversion
External reference
Low current LDO for voltage regulation
Programming connector
MSP430 mixed-signal MCU
Interface connector

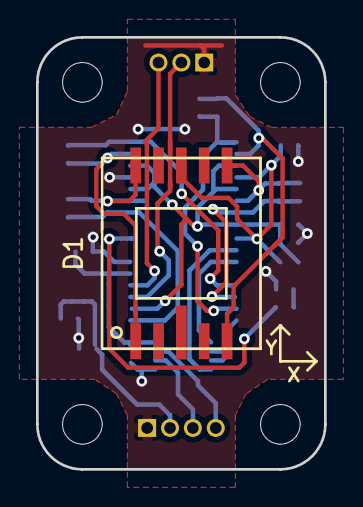
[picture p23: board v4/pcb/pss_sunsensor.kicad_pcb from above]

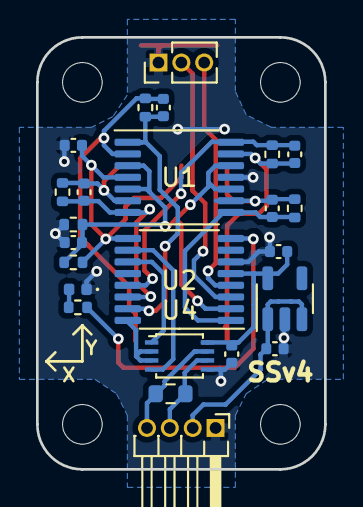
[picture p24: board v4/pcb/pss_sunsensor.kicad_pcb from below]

Board: 2 copper layers, 16.0 x 24.0 mm, 29 parts (24 on the bottom side), 22 nets.

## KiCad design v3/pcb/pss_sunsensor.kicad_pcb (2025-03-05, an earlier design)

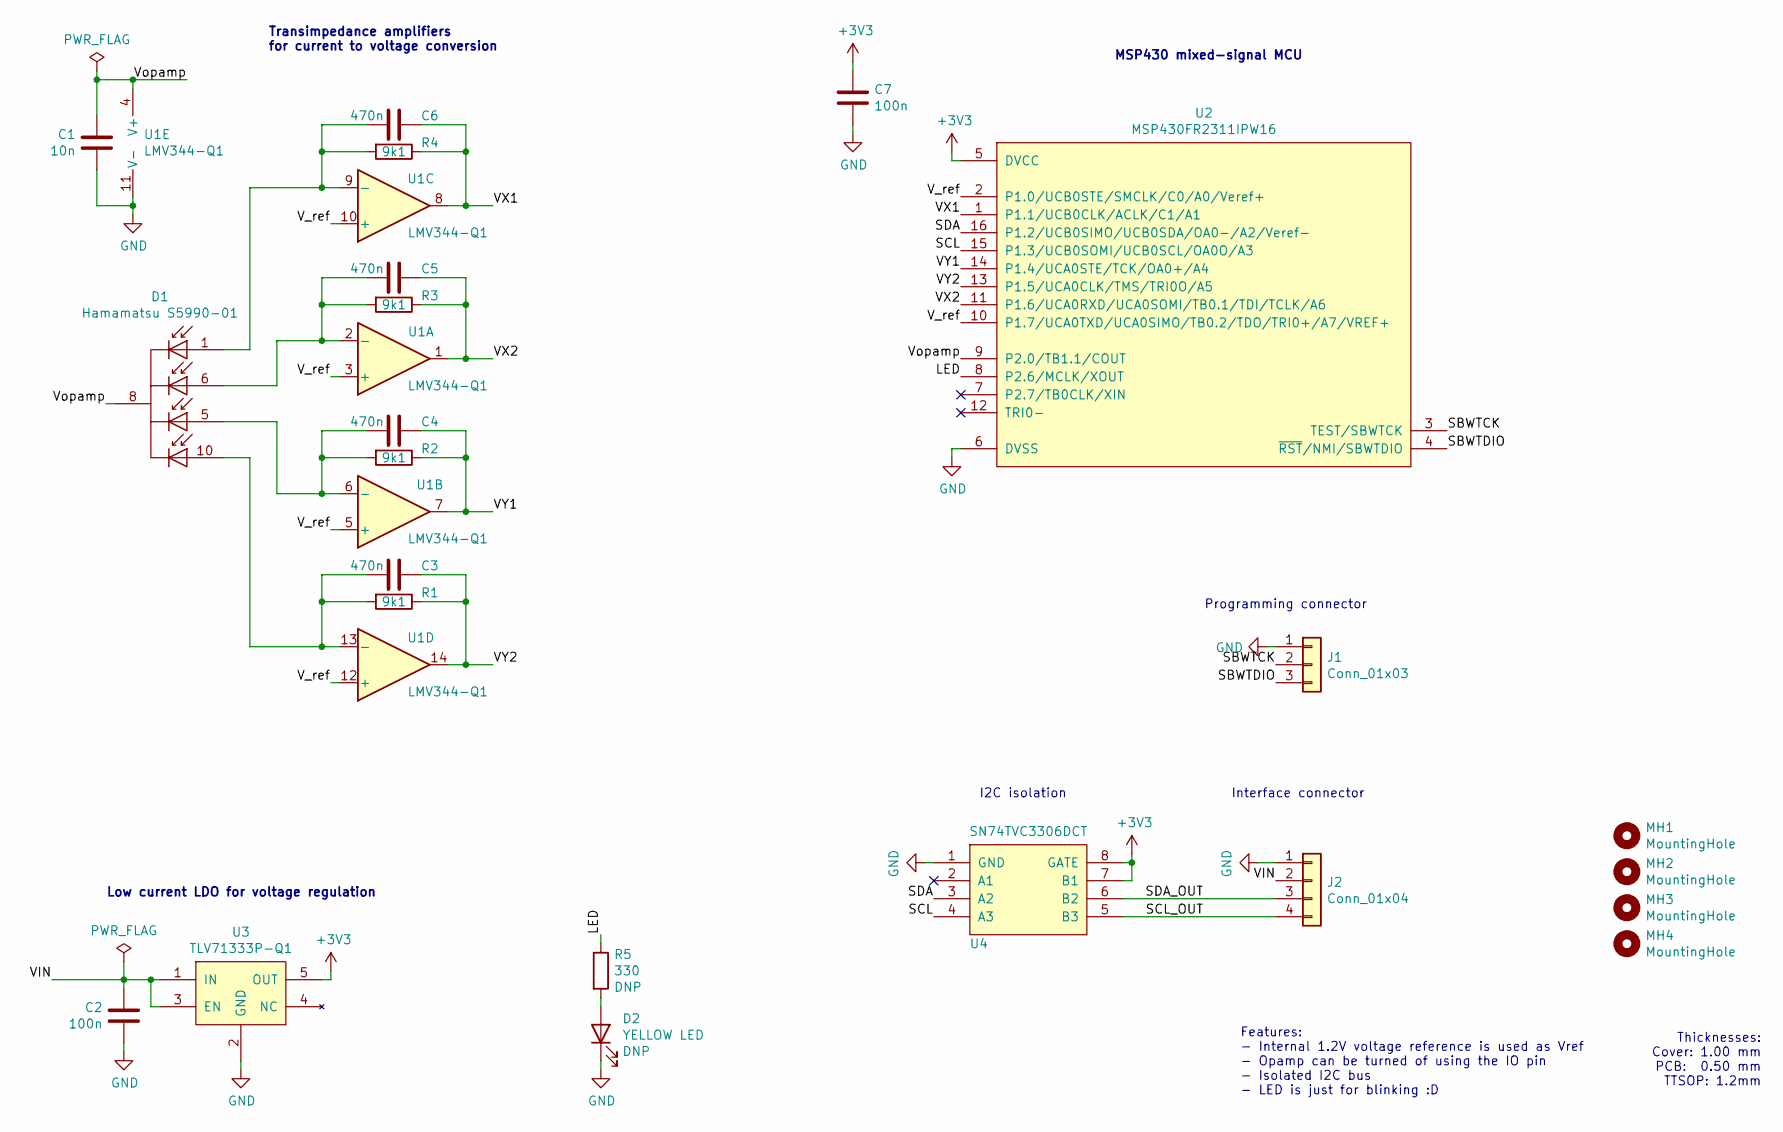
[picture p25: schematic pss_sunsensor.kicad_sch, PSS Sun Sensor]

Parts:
C1: 10n; C_0603_1608Metric
C2, C7: 100n; C_0603_1608Metric
C3, C4, C5, C6: 470n; C_0603_1608Metric
D1: Hamamatsu S5990-01; Hamatsu_S5980
D2: YELLOW LED; LED_0603_1608Metric
J1: Conn_01x03; PinHeader_1x03_P1.27mm_Vertical
J2: Conn_01x04; PinHeader_1x04_P1.27mm_Horizontal
MH1, MH2, MH3, MH4: MountingHole; MountingHole_2.2mm_M2
R1, R2, R3, R4: 9k1; R_0603_1608Metric
R5: 330; R_0603_1608Metric
U1: LMV344-Q1; TSSOP-14_4.4x5mm_P0.65mm; Mouser 595-LMV344IPWRQ1
U2: MSP430FR2311IPW16; TSSOP-16_4.4x5mm_P0.65mm; Mouser 595-P430FR2311IPW16R
U3: TLV71333P-Q1; SOT-23-5; Mouser 595-TLV71333PQDBVRQ1
U4: SN74TVC3306DCT; VSSOP-8_2.4x2.1mm_P0.5mm

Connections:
+3V3: C7.2, U2.5 (DVCC), U3.5 (OUT), U4.7 (B1), U4.8 (GATE)
/LED: R5.1, U2.8 (P2.6/MCLK/XOUT)
/SBWTCK: J1.2, U2.3 (TEST/SBWTCK)
/SBWTDIO: J1.3, U2.4 (~RST/NMI/SBWTDIO)
/SCL: U2.15 (P1.3/UCB0SOMI/UCB0SCL/OA0O/A3), U4.4 (A3)
/SCL_OUT: J2.4, U4.5 (B3)
/SDA: U2.16 (P1.2/UCB0SIMO/UCB0SDA/OA0-/A2/Veref-), U4.3 (A2)
/SDA_OUT: J2.3, U4.6 (B2)
/VIN: C2.2, J2.2, U3.1 (IN), U3.3 (EN)
/VX1: C6.1, R4.1, U1.8, U2.1 (P1.1/UCB0CLK/ACLK/C1/A1)
/VX2: C5.1, R3.1, U1.1, U2.11 (P1.6/UCA0RXD/UCA0SOMI/TB0.1/TDI/TCLK/A6)
/VY1: C4.1, R2.1, U1.7, U2.14 (P1.4/UCA0STE/TCK/OA0+/A4)
/VY2: C3.1, R1.1, U1.14, U2.13 (P1.5/UCA0CLK/TMS/TRI0O/A5)
/V_ref: U1.3 (+), U1.5 (+), U1.10 (+), U1.12 (+), U2.2 (P1.0/UCB0STE/SMCLK/C0/A0/Veref+), U2.10 (P1.7/UCA0TXD/UCA0SIMO/TB0.2/TDO/TRI0+/A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)
/Vopamp: C1.2, D1.8 (Cathode), U1.4 (V+), U2.9 (P2.0/TB1.1/COUT)
GND: C1.1, C2.1, C7.1, D2.1 (K), J1.1, J2.1, U1.11 (V-), U2.6 (DVSS), U3.2 (GND), U4.1 (GND)
unnamed: C6.2, D1.1 (Anode_X1), R4.2, U1.9 (-)
unnamed: C5.2, D1.6 (Anode_X2), R3.2, U1.2 (-)
unnamed: C4.2, D1.5 (Anode_Y1), R2.2, U1.6 (-)
unnamed: C3.2, D1.10 (Anode_Y2), R1.2, U1.13 (-)
unnamed: D2.2 (A), R5.2

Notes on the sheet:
Programming connector
Features: - Internal 1.2V voltage reference is used as Vref - Opamp can be turned of using the IO pin - Isolated I2C bus - LED is just for blinking :D
MSP430 mixed-signal MCU
Thicknesses: Cover: 1.00 mm PCB: 0.50 mm TTSOP: 1.2mm
Transimpedance amplifiers for current to voltage conversion
Interface connector
Low current LDO for voltage regulation
I2C isolation

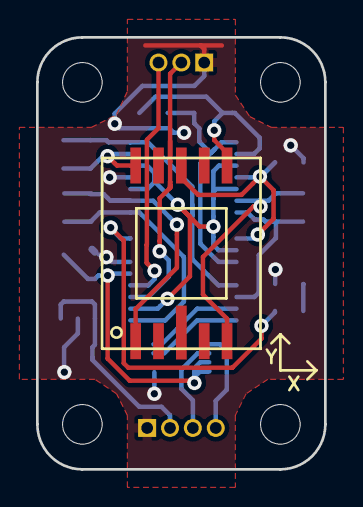
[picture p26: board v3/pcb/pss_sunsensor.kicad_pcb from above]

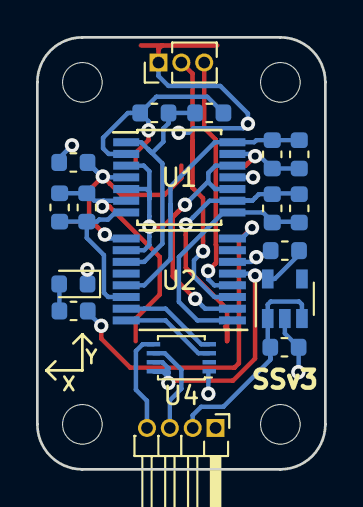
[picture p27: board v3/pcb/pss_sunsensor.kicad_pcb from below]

Board: 2 copper layers, 16.0 x 24.0 mm, 24 parts (19 on the bottom side), 21 nets.

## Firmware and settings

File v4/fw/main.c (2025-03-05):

#include <msp430.h>

#include "main.h"
#include "adc.h"
#include "telecommands.h"

static volatile int interrupt_pending = 0;

////////////////////////////////////////////////////////////////////////////////
/// Platform bus code
////////////////////////////////////////////////////////////////////////////////

#define RS485_PRI_DIR_TX() P1OUT |= BIT2
#define RS485_PRI_DIR_RX() P1OUT &= ~BIT2

typedef struct {
	int active_bus;

	const uint8_t* tx_buf;
	size_t tx_idx, tx_len;

	int slave_rxed;
} BusDriver;

#define BUS_ID_PRIMARY 0

BusFrame* bus_slave_receive(BusHandle* self) {
	BusDriver* driver = (BusDriver*)self->driver;
	if (driver->slave_rxed) {
		driver->slave_rxed = 0;
		return &self->frame_rx;
	}
	return NULL;
}

void bus_slave_send(BusHandle* self, BusFrame* rsp) {
	BusDriver* driver = (BusDriver*)self->driver;

	// Make sure interrupts are disabled. Technically they should
	// be by this point, because bus_slave_send() is called _ONLY_
	// after the slave has received and handled a frame
	UCA0IE = 0;

	// Prepare for transmitting
	const BusFrame* tx_frame = bus_prepare_tx_frame(rsp);
	driver->tx_buf = tx_frame->buf;
	driver->tx_len = tx_frame->len + BUS_OVERHEAD;
	driver->tx_idx = 0;

	// Begin transfer
	// NOTE: TX empty buffer flag needs to be set manually
	if (driver->active_bus == BUS_ID_PRIMARY) {
		RS485_PRI_DIR_TX();
		UCA0IFG = UCTXIFG;
		UCA0IE = UCTXIE;
	}
}

static BusHandle bus_adcs;

#if defined(__TI_COMPILER_VERSION__) || defined(__IAR_SYSTEMS_ICC__)
#pragma vector = TIMER1_B0_VECTOR
__interrupt void bus_rx_timeout_irq()
#elif defined(__GNUC__)
void __attribute__ ((interrupt(TIMER1_B0_VECTOR))) bus_rx_timeout_irq()
#else
#error Compiler not supported!
#endif
{
	TB1CTL &= ~MC__UPDOWN; // Put into stop mode

	bus_adcs.receive_timeouts++;

	bus_reset_rx(&bus_adcs);

	// Enable RX on bus
	RS485_PRI_DIR_RX();
	UCA0IE = UCRXIE;
}


#if defined(__TI_COMPILER_VERSION__) || defined(__IAR_SYSTEMS_ICC__)
#pragma vector=USCI_A0_VECTOR
__interrupt void bus_primary_irq()
#elif defined(__GNUC__)
void __attribute__ ((interrupt(USCI_A0_VECTOR))) bus_primary_irq()
#else
#error Compiler not supported!
#endif
{
	BusDriver* driver = (BusDriver*)bus_adcs.driver;

    switch(__even_in_range(UCA0IV, USCI_UART_UCTXCPTIFG)) {
        case USCI_NONE: break;
        case USCI_UART_UCRXIFG: { // Receive buffer full
        	driver->active_bus = BUS_ID_PRIMARY;

        	// Enable receiver timeout timer
        	TB1CTL |= MC__UP | TBCLR;
			TB1CCTL0 = CCIE;

        	if (bus_handle_rx_byte(&bus_adcs, UCA0RXBUF)) {
        		// Disable timer
				TB1CTL &= ~MC__UPDOWN;
				TB1CCTL0 = 0;

        		// After receiving successfully a frame appointed to our device,
				// disable receiver to make sure rx buffer won't get corrupted.
				// Next function to be called is bus_slave_send().
				UCA0IE = 0;

				// Wake up the main thread.
				driver->slave_rxed = 1;
				interrupt_pending = 1;
				__bic_SR_register_on_exit(LPM0_bits);
        	}
        } break;
        case USCI_UART_UCTXIFG: { // Transmit buffer empty
        	if (driver->tx_idx < driver->tx_len) {
        		UCA0TXBUF = driver->tx_buf[driver->tx_idx++];
        	} else {
        		UCA0IFG &= ~UCTXCPTIE; // NOTE: must be cleared or ISR will trigger on the previous byte
        		UCA0IE = UCTXCPTIE;
        	}
        } break;
        case USCI_UART_UCSTTIFG: { // Start bit received
        	UCA0IFG &= ~UCSTTIFG;
        } break;
        case USCI_UART_UCTXCPTIFG: { // Transmit complete
        	UCA0IE = 0;
        	UCA0IFG &= ~UCTXCPTIE;

        	// Go to receiver mode on bus
        	RS485_PRI_DIR_RX();
			UCA0IE = UCRXIE;
        } break;
        default: break;
    }
}

////////////////////////////////////////////////////////////////////////////////
/// Platform initialization and main loop
////////////////////////////////////////////////////////////////////////////////


volatile uint16_t sys_ticks = 0;

unsigned int idle_counter = ~0;
void reset_idle_counter(){
    idle_counter = 0;
}

// Sleep mode indicator flag. Sleep Mode - 0, Enabled - 1
uint8_t sleep_mode = 1;
void sleepmode() {

	OPAMP_OFF();

	PMMCTL0_H = PMMPW_H; // Unlock PMM
	PMMCTL2 &= ~INTREFEN; // Disable internal voltage reference
	PMMCTL2 &= ~TSENSOREN; // Disable internal temperature sensor
	ADCCTL0 &= ~ADCON; // Disable ADC
	PMMCTL0_H = 0; // Lock PMM

	sleep_mode = 1;
}

void wakeup() {

	OPAMP_ON();

	PMMCTL0_H = PMMPW_H; // Unlock PMM
	PMMCTL2 |= INTREFEN; // Enable internal voltage reference
	PMMCTL2 |= TSENSOREN; // Enable internal temperature sensor
	ADCCTL0 |= ADCON; // Enable ADC
	PMMCTL0_H = 0; // Lock PMM

	__delay_cycles(400);  // Delay for stuff to settle

	sleep_mode = 0;
}

/*
 * Watchdog time configuration
 *
 * Select master clock as the clock source WDT is cleared only in the heartbeat interrupt,
 * so the reset time must be greater than maximum heartbeat period.
 * VLOCLK_frq = 10kHz
 * WDTSSEL__ACLK = 32kHz
 * Reset Time [sec] = (2^X) / CLK_SOURCE
 * See WDTIS for values of X
 * WDTIS__512K = 16s
 */
#ifdef USE_WDT
#define RESET_WDT() (WDTCTL = WDTPW + WDTSSEL__ACLK + WDTIS__32K + WDTCNTCL)
#else
#define RESET_WDT() (WDTCTL = WDTPW + WDTHOLD) // Disabled!
#endif


void configure_clocks() {
    // Configure one FRAM waitstate as required by the device datasheet for MCLK
    // operation beyond 8MHz _before_ configuring the clock system.
    FRCTL0 = FRCTLPW;
    FRCTL0 = FRCTLPW | NWAITS_1; // 0xffff; PAOUT=0x0000; // Ports 1 and 2

    // To configure the DCO frequency or FLL reference clock with DCO factory trim, first clear the CSCTL0
    // register. This makes sure that the DCO starts from the lowest frequency to avoid a frequency above
    // specification due to temperature or supply voltage drift over time. Wait at least two MCLK cycles before
    // the FLL is enabled. After the wait cycles, poll the FLLUNLOCK bits to determine if the FLL is locked in the
    // target frequency range.
    // The recommended process to configure the FLL is:
    // 1. Disable the FLL.
    // 2. Select the reference clock.
    // 3. Clear the CSCTL0 register.
    // 4. Set the DCO range and set FLLN and FLLD for target frequency.
    // 5. Execute NOP three times to allow time for the settings to be applied.
    // 6. Enable the FLL.
    // 7. Poll the FLLUNLOCK bits until the FLL is locked.

    // Configure DCO & FLL
    __bis_SR_register(SCG0);    // Disable FLL
    CSCTL3 |= SELREF__REFOCLK;  // Select reference clock source for FLL
    CSCTL0 = 0;                // Clear the CSCTL0 register.
    CSCTL1 |= DCORSEL_5;        // Set DCO range to 16MHz
    CSCTL2 |= FLLD__1 | 243;    // Set target frequency (16MHz) for FLL
                                // DCOCLK = 2^FLLD * (FLLN +1) * (FLLRefclk/n)
                                // DCOCLKDIV = (FLLN +1) * (FLLRefclk/n)
                                // n = FLLREFDIV (fixed to 1 for 32kHz)
                                // 2^1 *(243 + 1) * 32768 Hz = 16MHz
                                // (243 + 1) * 32768 Hz = 8MHz
                                // Set FLL Div = fDCOCLK/1
    // allow time for settings to be applied
    __delay_cycles(3);
    __bic_SR_register(SCG0);    // Enable the FLL control loop


    // Set clock distribution
    CSCTL4 = SELMS__DCOCLKDIV | SELA__REFOCLK; // SELA: set default REFO(~32768Hz) as ACLK source, ACLK = 32768Hz
                                               // SELMS: MCLK and SMCLK are sourced from DCOCLKDIV, providing a clock frequency DCOCLK÷2

    // Step 7: Poll the FLLUNLOCK bits until the FLL is locked
    while (CSCTL7 & FLLUNLOCK) {
        // FLL is not locked yet
    }
    // Reset Unlock history
    CSCTL7 &= ~FLLUNLOCKHIS;

    // Set reset on drifting clock: If the FLLULPUC bit is set,
    // a reset (PUC) is triggered if FLLULIFG is set.
    CSCTL7 |= FLLULPUC;
}

void init_gpio(void){
    // turn off everything to save power
    PADIR=0xffff; PAOUT=0x0000; // Ports 1 and 2
    // do individual config

    /** Configure PORT1 */
    // P1.0 = VREF              Analog Ref IN
    // P1.1 = VY2               Analog 1 IN
    // P1.2 = DE                RS485 ENable
    // P1.3 = VY1               Analog 3 IN
    // P1.4 = VX2               Analog 4 IN
    // P1.5 = VX1               Analog 5 IN
    // P1.6 = RX                UART RX
    // P1.7 = TX                UART TX
    // if version == (v4 or v4.5):
    // P1.1 = VX1               Analog 1 IN
    // P1.3 = VX2               Analog 3 IN
    // P1.4 = VY1               Analog 4 IN
    // P1.5 = VY2               Analog 5 IN

    // Setup analog inputs
    P1SEL0 |= BIT0 | BIT1 | BIT3 | BIT4 | BIT5;
    P1SEL1 |= BIT0 | BIT1 | BIT3 | BIT4 | BIT5;

    // PMM
    PMMCTL0_H = PMMPW_H; // Unlock PMM
    PMMCTL2 |= INTREFEN; // Enable internal reference
    PMMCTL2 |= TSENSOREN; // Enable internal temperature sensor
    PMMCTL0_H = 0; // Lock PMM

    /** Configure PORT2 */
    // P2.0 = Vopamp          OUT
    // P2.6 = LED             OUT
    // P2.7 = Unconnected pin used for timing analysis
    P2DIR |= BIT0 | BIT6 | BIT7;
    P2OUT = 0; // Opamp and LED are off by default
}


void init_heartbeat_timer() {
	/*
	 * Configure TimerB0
	 *
	 * SMCLK = DCOCLKDIV
	 * Timer frequency(Hz) = SMCLK / (TB0CCR0 * 8 * 8)
	 * TB0CCR0 = SMCLK / (timer_frequency(Hz)*8*8)
	 * add 50 for every 1000, was measured to be more spot on at 16ms at room temp
	 */

	TB0CTL = MC__UP + TBSSEL__SMCLK + ID__8;    // UP mode, SMCLK, divide by 8
	TB0CCR0 = 2100;                             // up to this count
	TB0EX0 = TBIDEX__8;                         // Divide by 8
	TB0CCTL0 = CCIE;                            // TACCR0 interrupt enabled
	TB0CTL |= TBCLR;
	TB0R = 0;
}


/*
 * Timer B0 interrupt (triggering every 16ms)
 */
 #if defined(__TI_COMPILER_VERSION__) || defined(__IAR_SYSTEMS_ICC__)
#pragma vector = TIMER0_B0_VECTOR
__interrupt void Timer_B0()
#elif defined(__GNUC__)
void __attribute__ ((interrupt(TIMER0_B0_VECTOR))) Timer_B0()
#else
#error Compiler not supported!
#endif
{
    sys_ticks++; // sys_tick every 16 ms
	// Wake up the main loop
    LED_TOGGLE();
    RESET_WDT();
	__bic_SR_register_on_exit(LPM0_bits);
}



////////////////////////////////////////////////////////////////////////////////
/// Platform initialization and main loop
////////////////////////////////////////////////////////////////////////////////

static void platform_init() {
	__disable_interrupt();

	WDTCTL = WDTPW | WDTHOLD;

	// Pin configuration
	{
		/*
		* 2) Initialize all control IO pins
		*/
		init_gpio();

		// P1.7 = TXD (SEL1.6=0, SEL0.7=1)
		// P1.6 = RXD (SEL1.6=0, SEL0.6=1)
		P1SEL0 |= BIT6 | BIT7;
		P1SEL1 &= ~(BIT6 | BIT7);
		P1DIR = BIT2;
		P1OUT = 0;
	}

	// UART reception timeout timer configuration
	{
		TB1CTL = TBSSEL__SMCLK | ID__8 | MC__UP;
		TB1CCTL0 = 0;
		TB1R = 0;
		TB1CCR0 = 399; // 0.2 msec
	}

	// UART configuration
	{
		// UCA1 (primary)
		UCA0CTLW0 = UCSWRST;                    // Set the state machine to reset
		UCA0CTLW0 |= UCSSEL__SMCLK;             // SMCLK

		// 115200 (see MSP430FR2311 User's Guide page 586)
        // https://e2e.ti.com/support/microcontrollers/msp-low-power-microcontrollers-group/msp430/f/msp-low-power-microcontroller-forum/478726/msp430fr4133-eusci_a-uart-settin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

        UCA0MCTLW |= UCOS16;                    // Oversampling enabled

        // Proper UART 115200 baud rate
        //UCA0BRW = 4;                            // Set the baud rate to 115200 (8MHz)
        //UCA0MCTLW |= UCBRF_5 | 0x5500;          // Modulation UCBRSx=0x55, UCBRFx=5

        // Baud rate of OBC is 3% (111607) slower AND MESSES UP EVERYTHING
		UCA0BRW = 4;                            // Set the baud rate to 115200 (8MHz)
		UCA0MCTLW |= UCBRF_10 | 0xB700;          // Modulation UCBRSx=0xB7, UCBRFx=10

		UCA0CTLW0 &= ~UCSWRST;                  // Release the reset
		UCA0IE |= UCRXIE;                       // Enable USCI_A0 RX interrupt

		// Enable RX
		RS485_PRI_DIR_RX();
		UCA0IE = UCRXIE;
	}



	/*
	 * 1) Initialization of clocks
	 */
	configure_clocks();


	// Disable the GPIO power-on default high-impedance mode to activate
	// previously configured port settings
	PM5CTL0 &= ~LOCKLPM5;

	/*
	 * 3) Initialize other peripherals
	 */

	init_adc();
	init_heartbeat_timer();

	sleepmode();

	/*
	 * 4) Start normal operation aka listen UART and other interrupts.
	 */

	__bis_SR_register(GIE); // Enable interrupts
	__no_operation(); // First chance for the interrupt to fire!

	RESET_WDT();

	LED_ON();
}

static void platform_loop() {
	BusDriver bus_driver = { 0 };
	bus_adcs.driver = &bus_driver;

	for (;;) {

		RESET_WDT();

		// Make sure that all interrupts are serviced before going to sleep
		__disable_interrupt();
		if (!interrupt_pending) {
			__bis_SR_register(LPM0_bits | GIE);
		}
		interrupt_pending = 0;
		__enable_interrupt();

		// Update slave bus
		{
			BusFrame* cmd = bus_slave_receive(&bus_adcs);
			if (cmd != NULL) {
				BusFrame* rsp = bus_get_tx_frame(&bus_adcs);
				handle_command(cmd, rsp);
				bus_slave_send(&bus_adcs, rsp);
			}
		}

		TB0CTL |= TBCLR;

		// Processor wakes up every 16ms --> Goes to sleep after 16ms*250 = 4s
		if (idle_counter > 250 && !sleep_mode) {
			// Goto "deepsleep" if rs485 is not actively used
			sleepmode();
		}
		else {
			idle_counter++;
			// Resets itself after 16ms*1250 = 20s
			if (idle_counter >= 1250) {
				// Trigger POR reset after ~20 seconds of idling
				PMMCTL0 |= PMMSWPOR;
			}
		}
	}
}

int main() {
    platform_init();
    platform_loop();

    return 0;
}

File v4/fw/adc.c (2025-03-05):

#include <msp430.h>
#include "main.h"
#include "calc.h"

volatile int adc_done;
volatile int samples_todo;
volatile int16_t temperature_raw;

#define CAL_ADC_15T30  *((uint16_t *)0x1A1A)   // Temperature Sensor Calibration-30 C for 1V5 (value around 675)
                                               // See device-specific datasheet for TLV table memory mapping
#define CAL_ADC_15T85  *((uint16_t *)0x1A1C)   // Temperature Sensor Calibration-85 C for 1V5 (value around 802)


/*
 * Port 2.7 can be used for timing analysis purposes
 */
#if 0
#define START_TIMING()  P2OUT |=  BIT7
#define STOP_TIMING()   P2OUT &= ~BIT7
#else
#define START_TIMING()
#define STOP_TIMING()
#endif

void init_adc(void)
{
	// Configure ADC - Pulse sample mode; ADCSC trigger
	ADCCTL0 = ADCSHT_2 | ADCON;                                         // S&H = 16 ADCCLKs; ADC ON
	ADCCTL1 = ADCSHS_0 | ADCSHP_1 | ADCCONSEQ_0 | ADCDIV_0 | ADCSSEL_1; // S/W trig, ACLK(REFCLK(32kHz)))/1, single ch/conv
	ADCCTL2 = ADCRES_1 | ADCDF_0 | ADCSR;                               // 10-bit conversion results, unsigned, 50ksps

	ADCIE |= ADCIE0;                                                    // Enable the interrupt request for a completed ADC conversion
}


void read_voltage_channels()
{

	START_TIMING();

	/* Wakeup the opamp and ADC if needed */
	if (sleep_mode)
		wakeup();

	/* Wait for existing conversion */
	unsigned int i = 100;
	while ((ADCCTL1 & ADCBUSY) && i-- > 0)
		__no_operation();

	// reset raw values
	raw.vx1 = raw.vx2 = raw.vy1 = raw.vy2 = 0;

	adc_done = 0;
	samples_todo = calibration.samples;
	// prevent wrong calibration values
	if (samples_todo == 0 || samples_todo % 2 != 0)
		samples_todo = 1;

	ADCCTL0 &= ~ADCENC;                 // Force disable ADC for configuring
	ADCMCTL0 = ADCSREF_2 + ADCINCH_5;   // Select first ADC input channel (VX1)
	ADCCTL0 |= ADCENC | ADCSC;          // Sampling and conversion start

	// interrupts for finished conversions will be triggered in sequence

	// Wait the ADC conversions to end
	i = 100;
	while (!adc_done && i-- > 0) {
		__bis_SR_register(LPM0_bits + GIE);
		__no_operation(); // Wait few ticks
		__no_operation();
		__no_operation();
	}

	adc_done = 0;

	if (i == 0) { // ADC is not able to conversion!
	    // set raw values to indicate wrong numbers
		raw.vx1 = raw.vx2 = raw.vy1 = raw.vy2 = 0xFFFF;
		return;
	}

	if (calibration.samples == 2) {
		raw.vx1 >>= 1; raw.vx2 >>= 1;
		raw.vy1 >>= 1; raw.vy2 >>= 1;
	}
	else if (calibration.samples == 4) {
		raw.vx1 >>= 2; raw.vx2 >>= 2;
		raw.vy1 >>= 2; raw.vy2 >>= 2;
	}
	else if (calibration.samples == 8) {
		raw.vx1 >>= 3; raw.vx2 >>= 3;
		raw.vy1 >>= 3; raw.vy2 >>= 3;
	}
	/*else if (calibration.samples == 16) {
		raw.vx1 >>= 4; raw.vx2 >>= 4;
		raw.vy1 >>= 4; raw.vy2 >>= 4;
	}
	else {
		raw.vx1 /= calibration.samples; raw.vx2 /= calibration.samples;
		raw.vy1 /= calibration.samples; raw.vy2 /= calibration.samples;
	}*/


	// raw = 1023-raw
	// XOR is more effective than subtraction
	raw.vx1 = 1023 ^ raw.vx1;
	raw.vx2 = 1023 ^ raw.vx2;
	raw.vy1 = 1023 ^ raw.vy1;
	raw.vy2 = 1023 ^ raw.vy2;

	STOP_TIMING();
}


int16_t read_temperature()
{
	START_TIMING();

	// Wakeup the opamp and ADC if needed
	if (sleep_mode)
		wakeup();

    // Wait for existing conversion
    uint8_t i = 100;
    while((ADCCTL1 & ADCBUSY) && i-- > 0)
        __no_operation();

    adc_done = 0;
    ADCCTL0 &= ~ADCENC; // Disable ADC
    ADCMCTL0 = ADCSREF_1 + ADCINCH_12; // Compare ADC channel 12 against 1.5V reference
    ADCCTL0 |= ADCENC + ADCSC; // Sampling and conversion start

    i = 100;
    while (!adc_done && i-- > 0) {
        __bis_SR_register(LPM0_bits + GIE);
        __no_operation(); // Wait few ticks
        __no_operation();
        __no_operation();
    }

    if (i == 0) { // ADC is not able to conversion!
        return 0xFFFF;
    }

    // int32_t needed because otherwise pre1 and 2 will overflow
	int32_t pre1 =  (temperature_raw - (int32_t)CAL_ADC_15T30)* (850 - 300);
	int32_t pre2 = (int32_t)CAL_ADC_15T85 - (int32_t)CAL_ADC_15T30;
	temperature_raw = (pre1 / pre2) + 300;

	STOP_TIMING();
    // Calculate calibrated temperature in deciCelciuses
    return (temperature_raw + calibration.temperature_bias);
}


// ADC10 interrupt service routine
#ifdef NO_CCS
void __attribute__ ((interrupt("adc"))) ADC_ISR(void)
#else
#pragma vector=ADC_VECTOR
__interrupt void ADC_ISR(void)
#endif
{
	switch(__even_in_range(ADCIV, 12))
	{
	case ADCIV__NONE: break;                // No interrupt
	case ADCIV__ADCOVIFG: break;            // conversion result overflow
	case ADCIV__ADCTOVIFG: break;           // conversion time overflow
	case ADCIV__ADCHIIFG: break;            // ADCHI
	case ADCIV__ADCLOIFG: break;            // ADCLO
	case ADCIV__ADCINIFG: break;            // ADCIN
	case ADCIV__ADCIFG0: {                  // ADCIFG0: End of conversion

		switch (ADCMCTL0 & 0x0F) {
#ifdef V4X
        // P1.1 = VX1               Analog 1 IN
        // P1.3 = VX2               Analog 3 IN
        // P1.4 = VY1               Analog 4 IN
        // P1.5 = VY2               Analog 5 IN
        case ADCINCH_5:                      // A5: VY2
			raw.vy2 += ADCMEM0;
			ADCCTL0 &= ~ADCENC;
			ADCMCTL0 = ADCSREF_2 + ADCINCH_4; // Enable conversion for next channel
			ADCCTL0 |= ADCENC + ADCSC;
			break;

		case ADCINCH_4:                      // A4: VY1
			raw.vy1 += ADCMEM0;
			ADCCTL0 &= ~ADCENC;
			ADCMCTL0 = ADCSREF_2 + ADCINCH_3; // Enable conversion for next channel
			ADCCTL0 |= ADCENC + ADCSC;
			break;

		case ADCINCH_3:                      // A3: VX2
			raw.vx2 += ADCMEM0;
			ADCCTL0 &= ~ADCENC;
			ADCMCTL0 = ADCSREF_2 + ADCINCH_1; // Enable conversion for next channel
			ADCCTL0 |= ADCENC + ADCSC;
			break;

		case ADCINCH_1:                      // A1: VX1
			raw.vx1 += ADCMEM0;
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
